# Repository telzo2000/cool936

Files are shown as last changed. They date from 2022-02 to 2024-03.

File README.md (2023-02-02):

# cool936

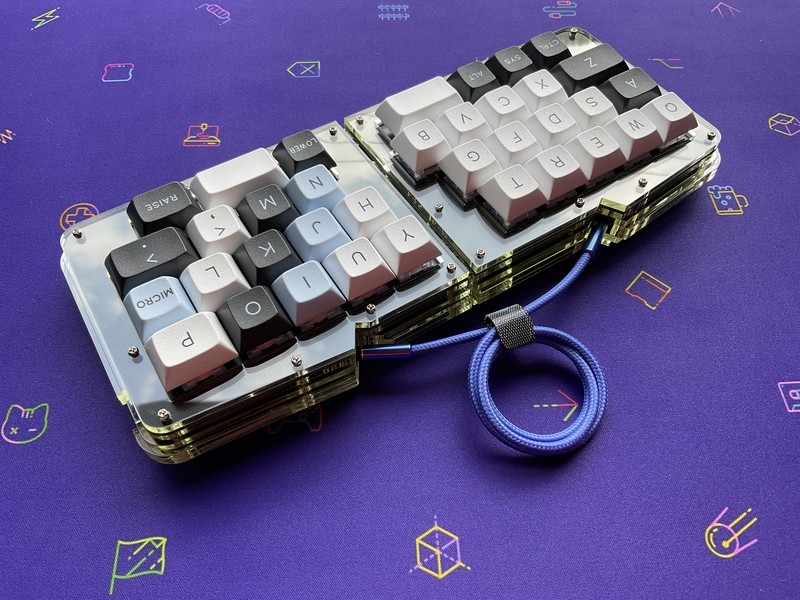
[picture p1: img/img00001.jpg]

## What is cool936?

cool936 is a split keyboard with a [qaz](https://www.cbkbd.com/product/qaz-keyboard-kit) layout.
<br>
[qaz](https://www.cbkbd.com/product/qaz-keyboard-kit)レイアウトの分割キーボードです。
<br>
<br>

## Build Guide
https://github.com/telzo2000/cool936/blob/main/buildguide_for_cool936.md

<br>

## Terms of use(使用条件)

You are free to duplicate the data related to cool936, place an order for PCB, etc. and use it personally.
<br>
cool936に関するデータを複製して、PCB等発注して個人で使用するのは自由です。
<br>
However, it is prohibited to give or receive money such as sales using the data ordered by an individual.
<br>
ただし、個人で発注したデータを使用して販売等、金銭の授受が発生することは禁止です。
<br>
The transfer of money as a manufacturing agent is also included in the prohibition.
<br>
製造代行と称しての金銭の授受も禁止に含まれます。
<br>
<br>

## What are coolxxx?

These keyboards is designed by m.ki.

|cool|another name|keyboard type|MCU|URL|Sales site|
| -- | -- | -- | -- | -- | -- |
|434|MyFirstMini|row|pro micro|none|none|
|445|none|row|pro micro & Raspberry Pi Pico|[Here](https://github.com/telzo2000/cool445)|[Here](https://mki0002ozlet.booth.pm/items/4069834)|
|536|none|column|pro micro|[Here](https://github.com/telzo2000/cool536)|[Here](https://mki0002ozlet.booth.pm/items/4190386)|
|536azcore|none|colum|AZ-CORE|[Here](https://github.com/telzo2000/cool536azcore)|[Here](https://mki0002ozlet.booth.pm/items/4424562)|
|544|Caravellion|column|pro micro|none|none|
|635|none|ortho|pro micro|[Here](https://github.com/telzo2000/cool635-)|none|
|640|none|ortho splite|pro micro & Raspberry Pi Pico|[Here](https://github.com/telzo2000/cool640) |[Here](https://mki0002ozlet.booth.pm/items/3729914)|
|644|none|ortho splite|pro micro|[Here](https://github.com/telzo2000/cool644)|[Here](https://mki0002ozlet.booth.pm/items/3729914)|
|640|none|ortho splite|pro micro & Raspberry Pi Pico | [Here](https://github.com/telzo2000/cool640)|[Here](https://mki0002ozlet.booth.pm/items/3729914) |
|640|none|ortho splite|pro micro & Raspberry Pi Pico|[Here](https://github.com/telzo2000/cool640)|[Here](https://mki0002ozlet.booth.pm/items/3729914)|
|650|none|ortho splite|pro micro|[Here](https://github.com/telzo2000/cool650)|[Here](https://mki0002ozlet.booth.pm/items/3585417)|
|664|none|ortho splite|pro micro|[Here](https://github.com/telzo2000/cool664)|[Here](https://mki0002ozlet.booth.pm/items/4328726)|
|753|none|row|pro micro|none|none|
|756|none|row|pro micro|[Here](https://github.com/telzo2000/cool756)|[Here](https://mki0002ozlet.booth.pm/items/4491960)|
|836A|none|alice|pro micro|[Here](https://github.com/telzo2000/cool836A)|[Here](https://mki0002ozlet.booth.pm/items/2542223)|
|836pico|none|alice|Raspberry Pi Pico|[Here](https://github.com/telzo2000/cool836pico)|[Here](https://mki0002ozlet.booth.pm/items/3391829)|
|836rp|none|alice|RP2040-Zero|[Here](https://github.com/telzo2000/cool836pico)|[Here](https://mki0002ozlet.booth.pm/items/3599330)|
|844|none|alice|pro micro|[Here](https://github.com/telzo2000/cool844)|[Here](https://mki0002ozlet.booth.pm/items/2805606)|
|844V2|none|alice|pro micro|[Here](https://github.com/telzo2000/cool844V2)|[Here](https://mki0002ozlet.booth.pm/items/3267681)|
|847|none|alice|pro micro|[Here](https://github.com/telzo2000/cool847)|[Here](https://mki0002ozlet.booth.pm/items/3358065)|
|936|none|row splite|pro micro|[Here](https://github.com/telzo2000/cool936)|none|
|939|none|row splite|pro micro|[Here](https://github.com/telzo2000/cool939)|none|
|943S|none|row splite|pro micro|[Here](https://github.com/telzo2000/cool943S)|[Here](https://mki0002ozlet.booth.pm/items/2901779)|
|950S|none|row splite|pro micro|[Here](https://github.com/telzo2000/cool950S)|[Here](https://mki0002ozlet.booth.pm/items/3160071)|
|959|none|alice splite|pro micro|[Here](https://github.com/telzo2000/cool959)|none|

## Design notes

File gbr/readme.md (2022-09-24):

## gbr data

ver.1.1 is a PCB compatible with sk6812mini-e.
<br>
ver.1.1はsk6812mini-eに対応したPCBです。
<br>
<br>
ver.151 is a PCB compatible with LED tape.
<br>
ver.151はLEDテープに対応したPCBです。
<br>

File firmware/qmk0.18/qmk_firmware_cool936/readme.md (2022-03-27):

# cool936

cool936

*A short description of the keyboard/project*

* Keyboard Maintainer: [m.ki](https://github.com/telzo2000)
* Hardware Supported: *The PCBs, controllers supported*
* Hardware Availability: *Links to where you can find this hardware*

Make example for this keyboard (after setting up your build environment):

    make cool936:default

Flashing example for this keyboard:

    make cool936:default:flash

See the [build environment setup](https://docs.qmk.fm/#/getting_started_build_tools) and the [make instructions](https://docs.qmk.fm/#/getting_started_make_guide) for more information. Brand new to QMK? Start with our [Complete Newbs Guide](https://docs.qmk.fm/#/newbs).

## Bootloader

Enter the bootloader in 3 ways:

* **Bootmagic reset**: Hold down the key at (0,0) in the matrix (usually the top left key or Escape) and plug in the keyboard
* **Physical reset button**: Briefly press the button on the back of the PCB - some may have pads you must short instead
* **Keycode in layout**: Press the key mapped to `RESET` if it is available

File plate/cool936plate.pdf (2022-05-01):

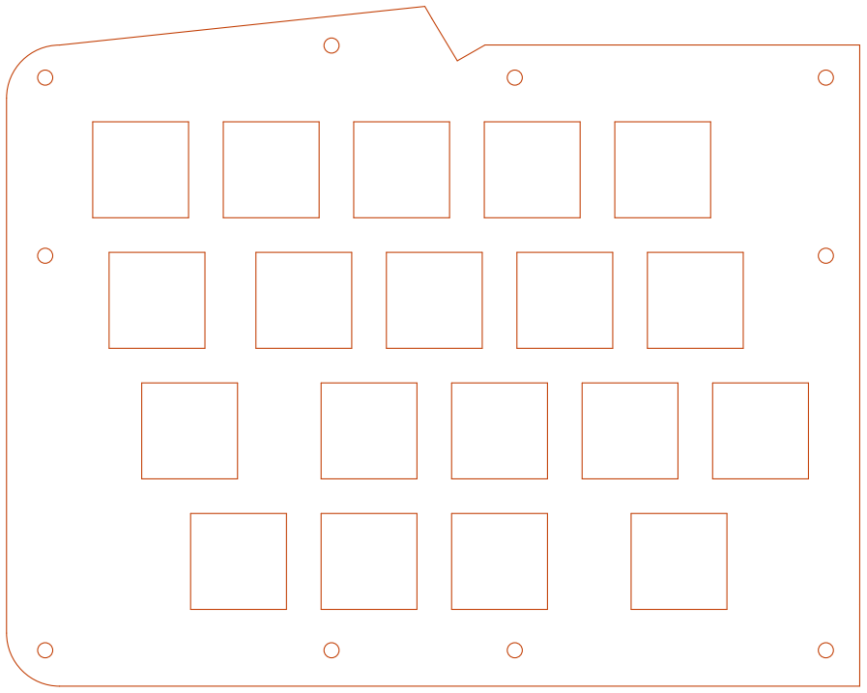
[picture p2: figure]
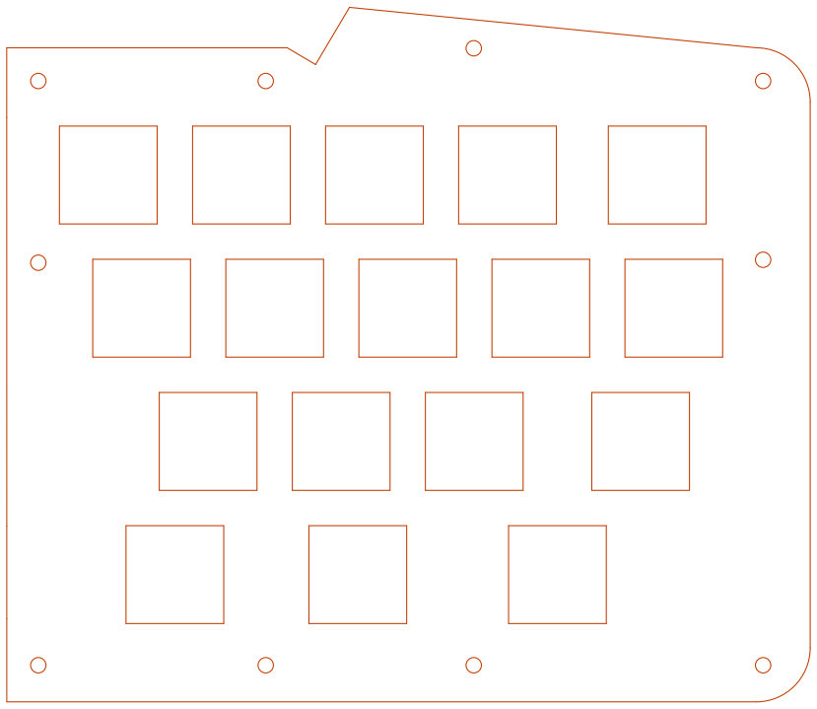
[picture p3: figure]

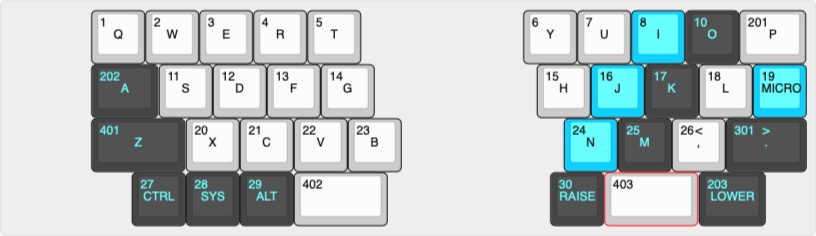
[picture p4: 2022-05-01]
first_design/cool936sbydss_micro-3.jpg

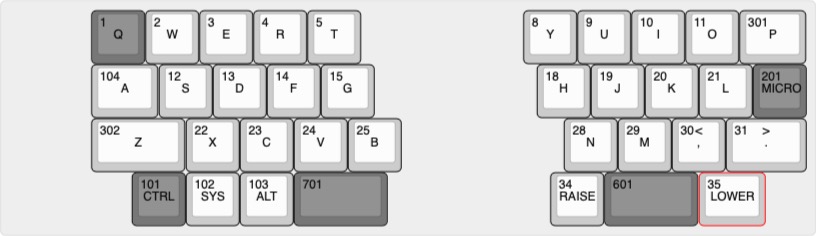
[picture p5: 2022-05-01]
first_design/cool936s.jpg

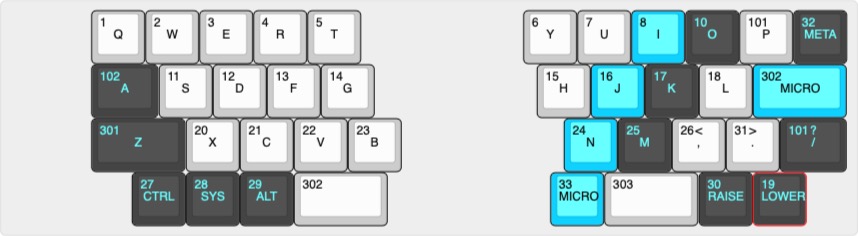
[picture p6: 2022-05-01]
first_design/cool939sbydss_micro-3.jpg

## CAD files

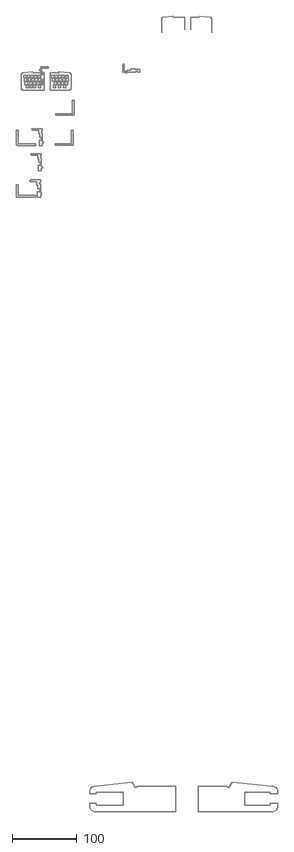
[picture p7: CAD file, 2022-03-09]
case/cool936casedesign02.dxf
404.4 x 1230.5

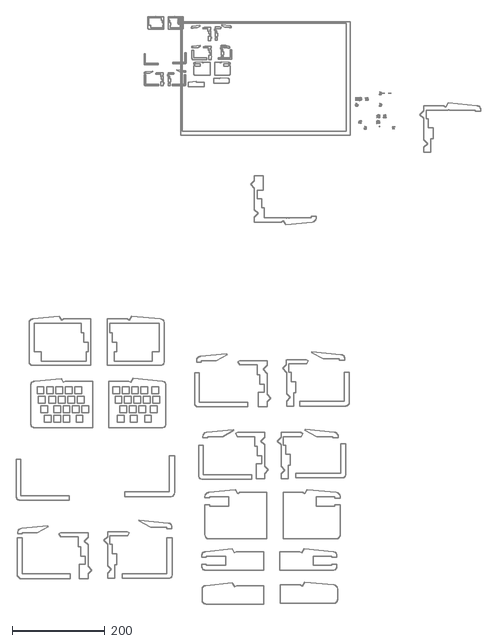
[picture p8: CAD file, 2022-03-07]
case_wide/Laser_450x300_template_inkscape_cool936.dxf
999.1 x 1264.5

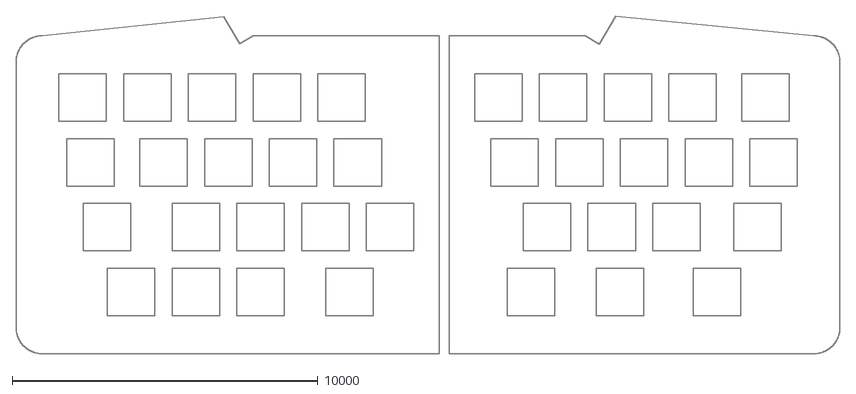
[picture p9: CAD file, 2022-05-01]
plate/cool936plate.dxf
26935.8 x 11036.7

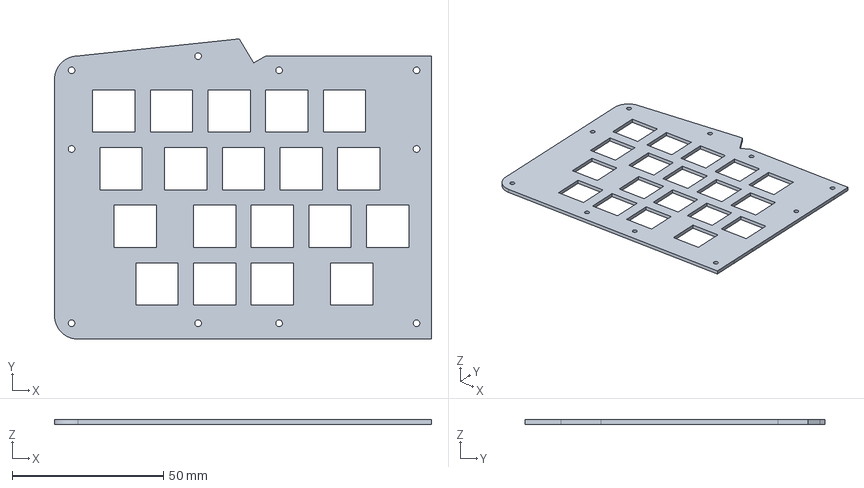
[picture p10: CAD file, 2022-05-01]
plate/plate_left/cool936plateleft.step
124.5 x 99.2 x 1.60 mm

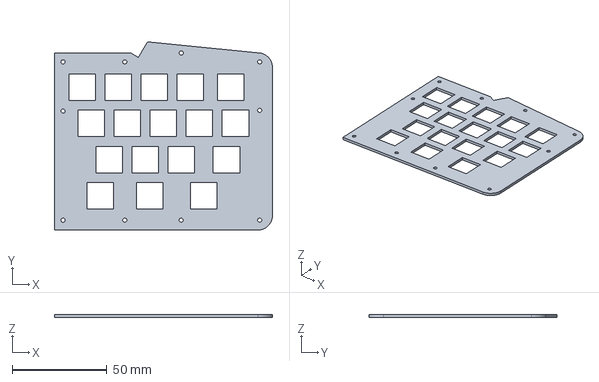
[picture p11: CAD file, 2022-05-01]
plate/plate_right/cool936plateright.step
115.0 x 99.3 x 1.60 mm

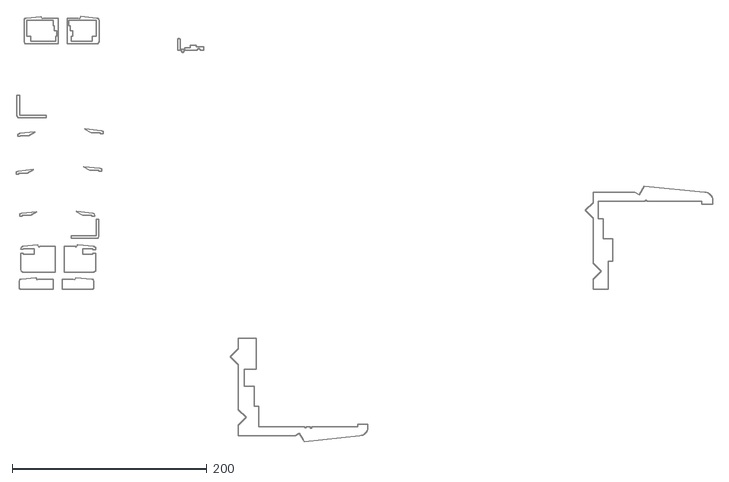
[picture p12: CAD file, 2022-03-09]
case/cool936casedesign01.dxf
714.9 x 436.3

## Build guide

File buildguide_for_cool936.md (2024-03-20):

# Build Guide

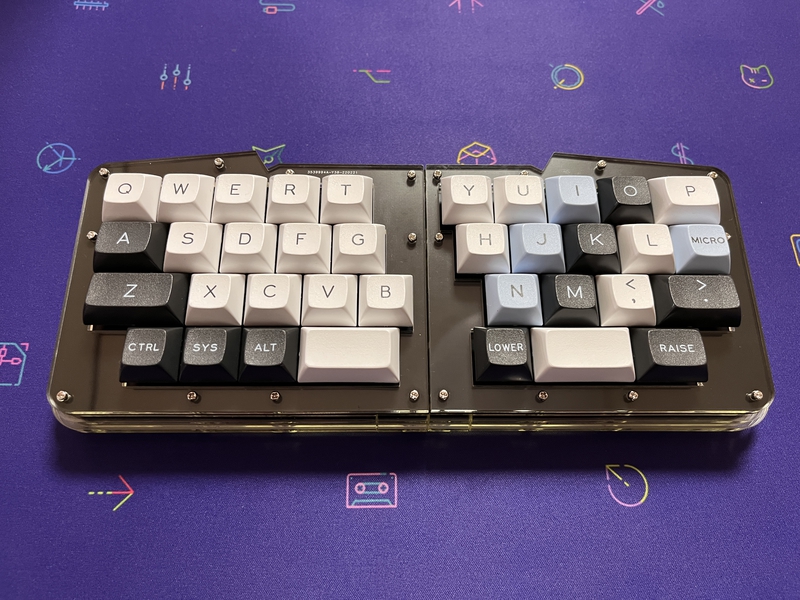
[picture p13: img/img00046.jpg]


## Parts List
Information as of March 8, 2022<br>
令和４年５月23日時点の情報
|番号| 名前 | 数 | 備考 | 調達先の例 | 参考価格 |
|:-|:-|:-|--|--|--|
|1|PCB Leftside|1|108.27 mm<br>* 86.87 mm|JLCPCB|５枚9.6ドル|
|2|PCB Rightside|1|98.87 mm<br>* 87.43 mm|↑|５枚で3.7ドル|
|3|Switch Plate|1|FR-4<br>左右一体で発注<br>242.4 mm<br>* 99.3 mm|↑|５枚で33.4ドル|
|4|Top Plate|左右１枚ずつ|アクリル3mm|※１|※２|
|5|Middle Plate|４層分（20個に分割）|アクリル3mm|※１|※２|
|6|Bottom Plate|２層分|アクリル3mm|※１|※２|
|7|M2ネジ|32|8mm<br>TopPlate側から20本挿入<br>BottomPlate側（奥）から12本挿入|DIYショップ等|10本程度で100円|
|8|M2ネジ|8|4mm<br>BottomPlate側（手前）から挿入|DIYショップ等|10本程度で100円|
|9|M2スペーサー|20|11mm丸型※３|[ヒロスギネット](https://www.hirosugi-net.co.jp/shop/default.aspx)<br>[遊舎工房](https://shop.yushakobo.jp)等|20個で748円（税込）@ヒロスギネット|
|10|Diode|36本|リードタイプ、SMDのどちらでも可|[遊舎工房](https://shop.yushakobo.jp)<br>[TALP keyboard](https://talpkeyboard.net)|100個で220円（税込）|
|11|Reset Switch|2|タクタイルスイッチとも|[遊舎工房](https://shop.yushakobo.jp)<br>[TALP keyboard](https://talpkeyboard.net)|1個で11円（税込）|
|12|Switch Socket|36|Cherry MX互換|[遊舎工房](https://shop.yushakobo.jp)<br>[TALP keyboard](https://talpkeyboard.net)|10個で165円（税込）|
|13|TRRS Jack|2||[遊舎工房](https://shop.yushakobo.jp)<br>[TALP keyboard](https://talpkeyboard.net)等|１個55円（税込）|
|14|pro micro|PCB１枚につき１個|ピンヘッダが必要|[遊舎工房](https://shop.yushakobo.jp)<br>[TALP keyboard](https://talpkeyboard.net)|時価|
|15|キーキャップ|36|[DSS Micro](https://mechvault.net/products/dss-micro-keycap-set)推奨<br>※４|[遊舎工房](https://shop.yushakobo.jp)<br>[TALP keyboard](https://talpkeyboard.net)|1個で100円前後<br>キーキャップセットで3000円程度から|
|16|TRRSケーブル|１本||[遊舎工房](https://shop.yushakobo.jp)<br>[TALP keyboard](https://talpkeyboard.net)等|300円程度から|
|17|ゴム足|８|任意|DIYショップ等|100円程度|

※１　[工房merge+](https://www.emergeplus.jp/laser-cutting-service/contact/)、[遊舎工房](https://shop.yushakobo.jp/collections/services/products/lasercut)、[Elecrow](https://www.elecrow.com/acrylic-cutting.html) 等でアクリル加工が可能。
<br>
※２　The [case folder](https://github.com/telzo2000/cool936/tree/main/case) contains two 300mmX300mm acrylic files, and the [case_wide folder](https://github.com/telzo2000/cool936/tree/main/case_wide) contains one 300mmX450mm acrylic file.
<br>
 [caseフォルダ](https://github.com/telzo2000/cool936/tree/main/case)には、300mmX300mmアクリル２枚、[case_wideフォルダ](https://github.com/telzo2000/cool936/tree/main/case_wide)には、300mmX450mmアクリル１枚にまとめられたファイルがある。
 <br>
※３　Due to the difference in acrylic accuracy, 11mm, which is slightly shorter than 12mm, is more suitable.
<br>アクリルの精度差により、12mmよりやや短い11mmの方が適当である。
<br>
※４　Since the cool936 is a QAZ-like keyboard, there are few keycaps to which the legend applies.
<br>
cool936は、QAZ的なキーボードなので、レジェンドが適応するキーキャップは少ない。
<br><br>
## 組み立て

### 0 アクリル部品の確認

cool936では、トッププレート、ミドルプレート、ボトムプレートにアクリル部品を使用するアクリル積層ケースとなっています。
<br>
トッププレートは左右それぞれ1枚ずつあります。
<br>
ミドルプレートは左右それぞれ４層となります。１層が２枚または３枚で構成されています。
<br>
ボトムプレートは左右それぞれ２層となります。大、小に分けられます。
<br>

### 左側<br>

トッププレート
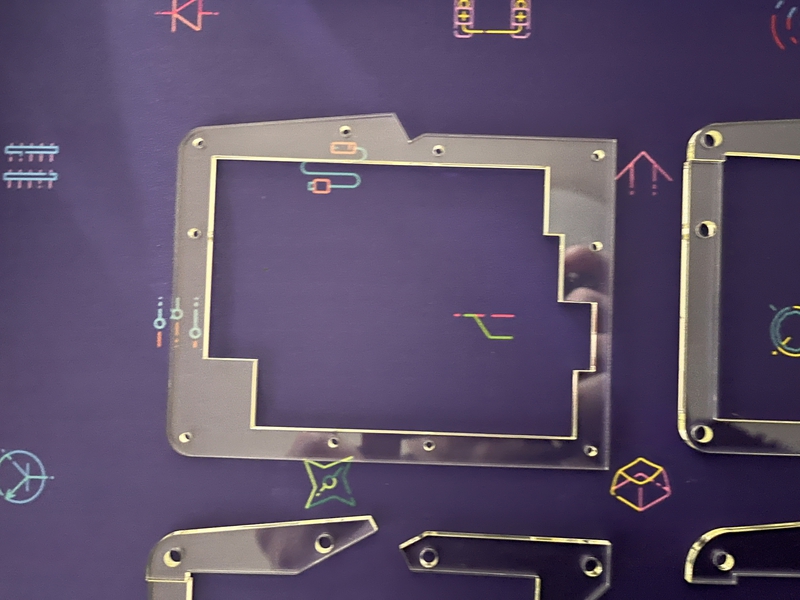
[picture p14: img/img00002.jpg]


ミドルプレート１
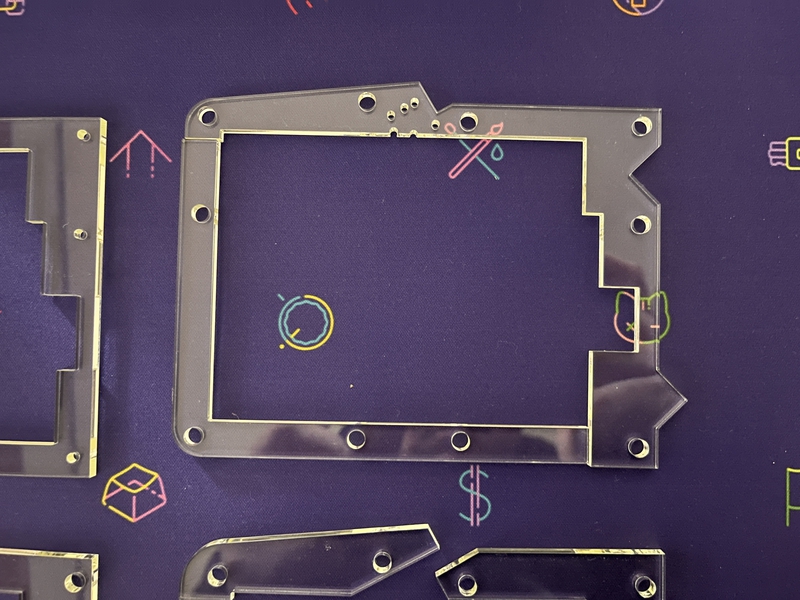
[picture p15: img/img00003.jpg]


ミドルプレート２
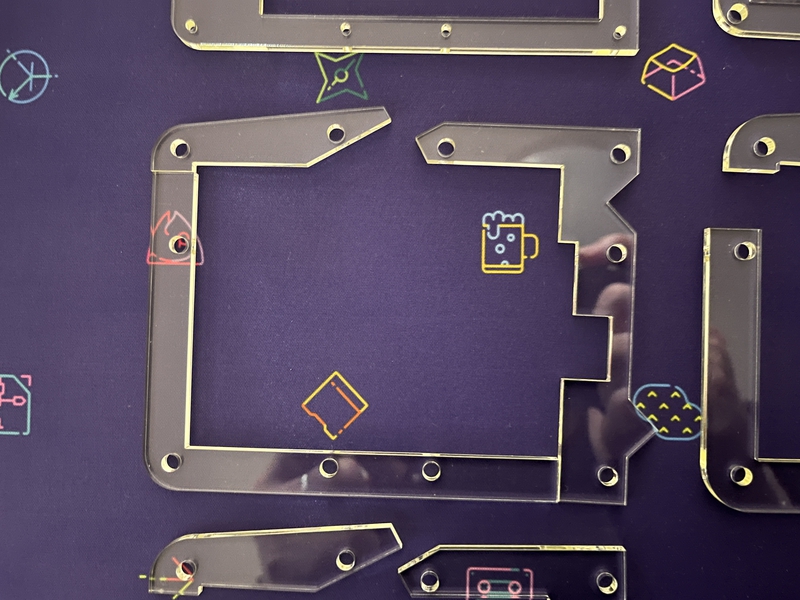
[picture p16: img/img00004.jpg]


ミドルプレート３・４（同じ形状）
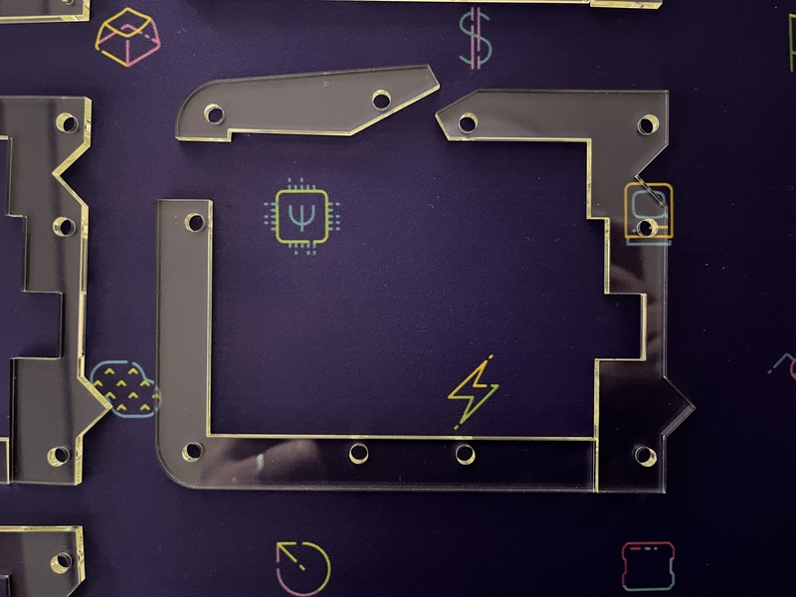
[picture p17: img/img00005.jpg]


ボトムプレート大
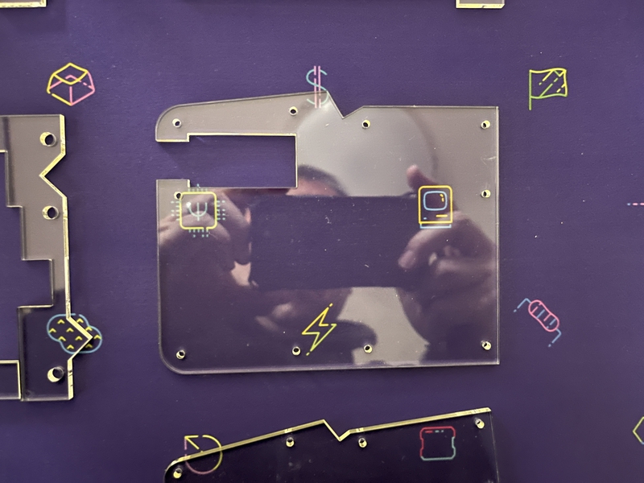
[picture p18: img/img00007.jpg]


ボトムプレート小
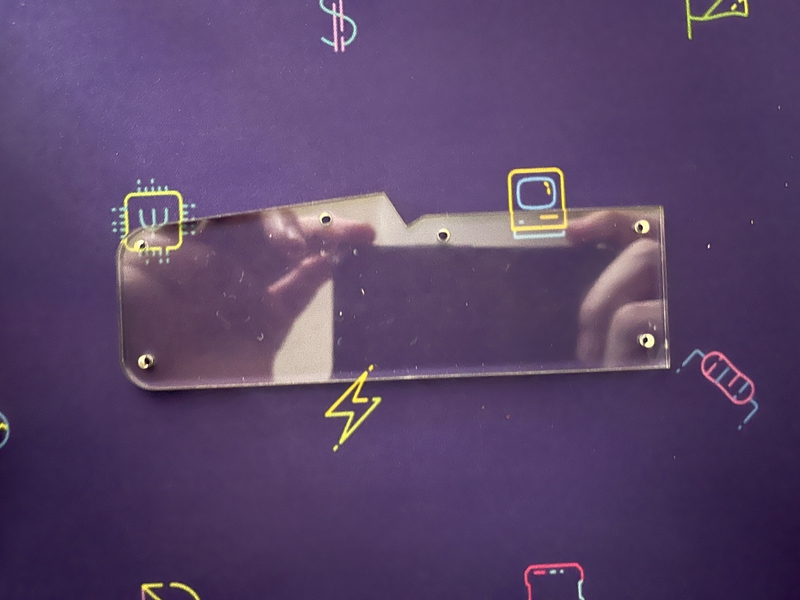
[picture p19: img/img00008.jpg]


### 右側<br>

トッププレート
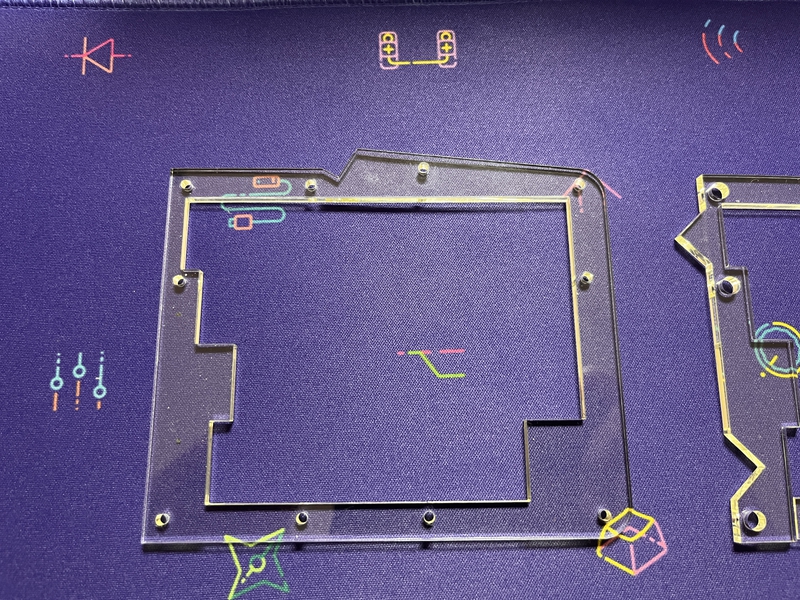
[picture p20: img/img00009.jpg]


ミドルプレート１
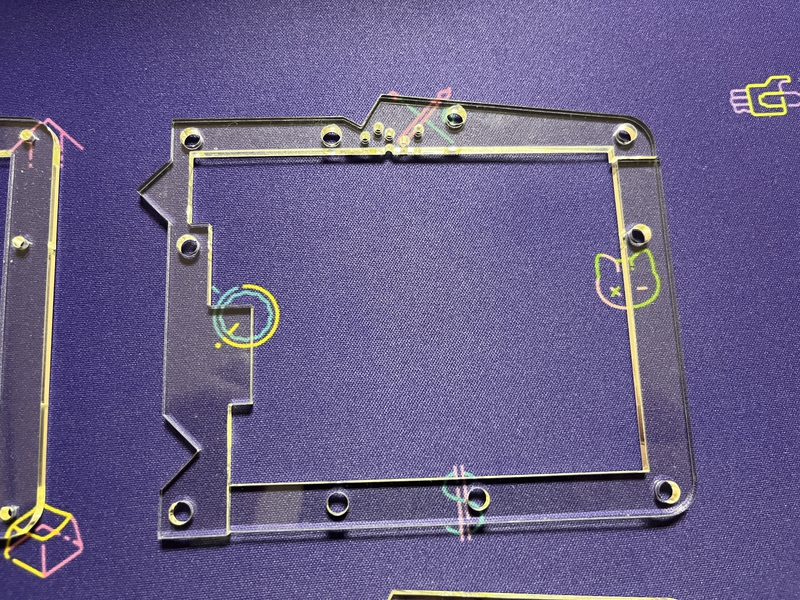
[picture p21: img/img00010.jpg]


ミドルプレート２
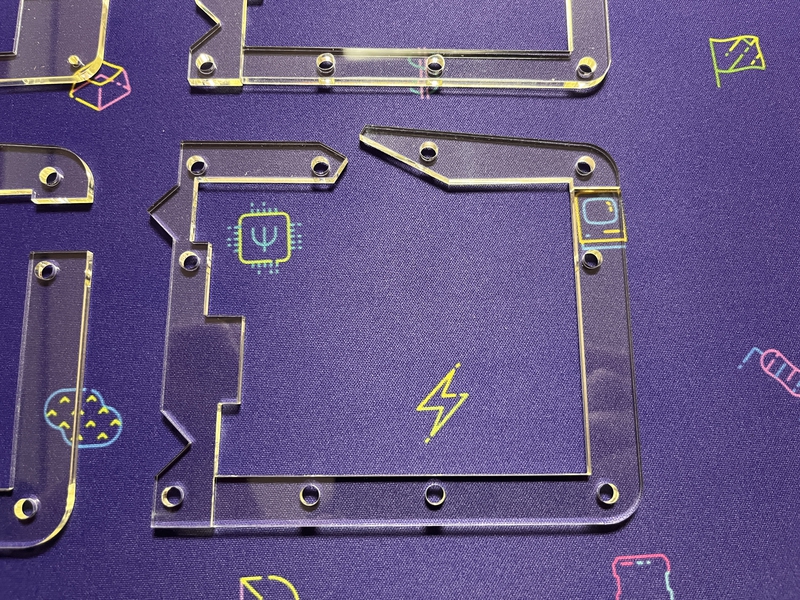
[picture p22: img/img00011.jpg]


ミドルプレート３・４（同じ形状）
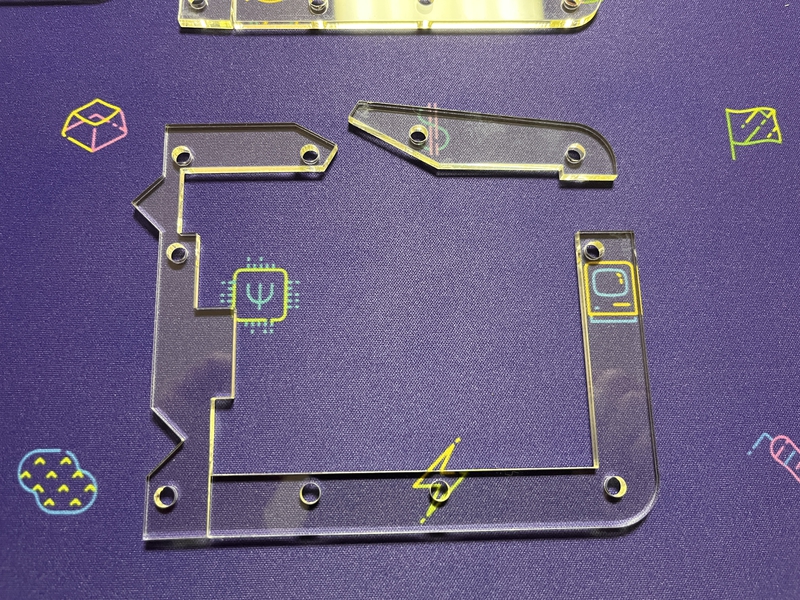
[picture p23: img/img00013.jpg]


ボトムプレート大
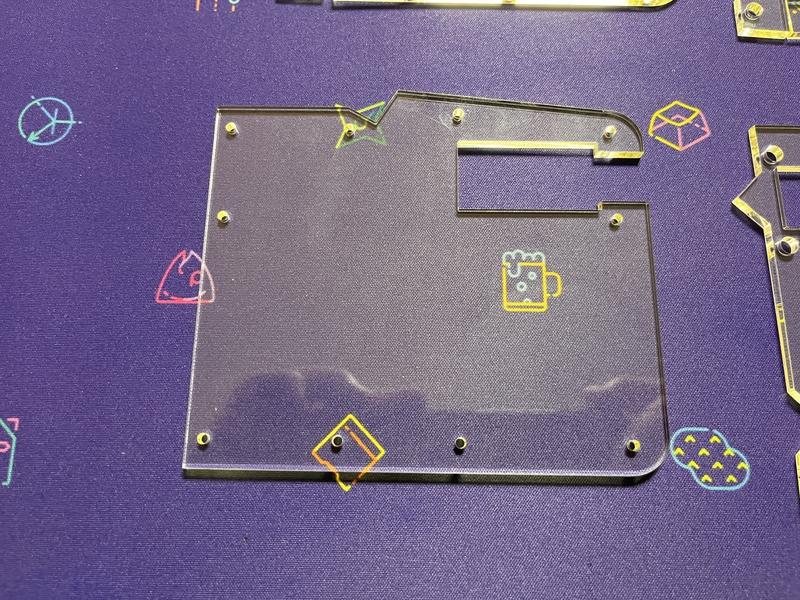
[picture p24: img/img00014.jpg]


ボトムプレート小
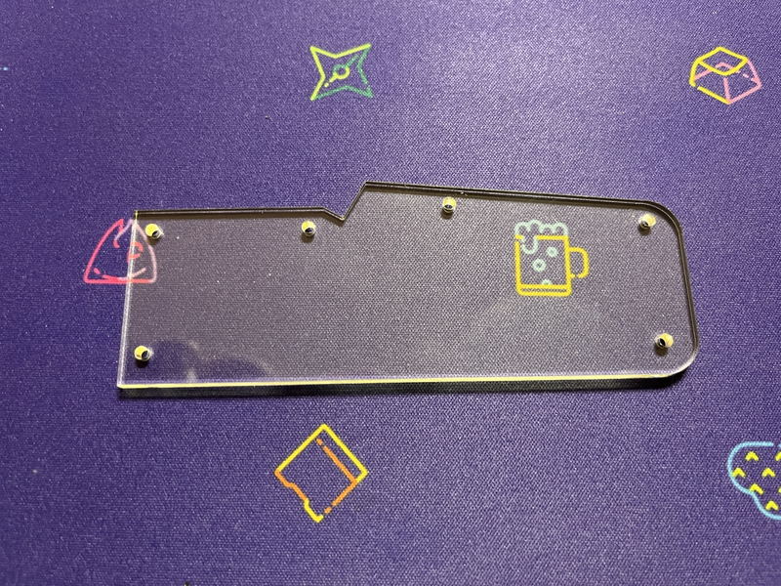
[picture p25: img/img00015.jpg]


### 1 ダイオードのハンダ付け

左右のPCBにそれぞれ、ダイオードをハンダ付けします。
<br>
構造上、どちらの面にハンダ付けしても問題ありませんが、
竜のイラストがある面にダイオードのハンダ付けをしてください。
<br>

### 2 スイッチソケットのはんだ付け

竜のイラストがある面に、スイッチソケットをハンダ付けします。
<br>
socketという文字が隠れるように、スイッチソケットを乗せると方向を間違えずに、
ハンダ付けができます。
<br><br>

### 3 リセットスイッチ、TRRSジャックのはんだ付け

竜のイラストがある面に、リセットスイッチ、TRRSジャックをハンダ付けします。
<br>
ハンダ付けした後、リセットスイッチとTRRSジャックのはみ出た足は、ニッパー等で切断しておいてください。
<br><br>

### 4 pro microの取り付け

竜のイラストがある面に、pro microを（できればスプリングヘッダを用いて）ハンダ付けしてください。
<br>
pro microの向きに注意が必要です。
<br>
pro microの部品が実装されている面が、下になるようにハンダ付けをしてください。
実際、逆に取り付けようとすると、pro microの部品と、先ほどハンダ付けしたスイッチソケットなどが干渉するので、
ハンダ付けができないと思います。
<br><br>

### 5 LEDのハンダ付け（任意）

後日、執筆予定。
<br><br>

### 6 仮テスト

一度スイッチを装着するか、ピンセットで接続するか等の方法でキー入力ができるかテストします。
<br>
[REMAP](https://remap-keys.app/)でファームウェアをインストールしてください。
<br>
[ここ](https://config.qmk.fm/#/test)でタイピングテストを行い、導通の確認をしてください。
<br>
すべてのキーの入力が確認できましたら、次の段階に進んでください。
<br>
うまくいかないキー入力がありましたら、温めたハンダゴテで、該当するスイッチソケット等のハンダを温め直してください。
<br><br>

参考<br>

https://github.com/telzo2000/Hello_keyboard/blob/main/readme_about_firmware.md

### 7　アクリルケースの組み立て
ボトムプレートからミドルプレートの順に、アクリル積層ケースを組み立てます。
<br>M２スペーサー11mmを20本（左右10本ずつ）、M２ネジ8mmを12本（左右6本ずつ）、２ネジ4mmを８本（左右４本ずつ）とミドルプレート２・３・４、ボトムプレート大・小を用意します。
<br>
### 左側

①ボトムプレート小から大の順で、M２ネジ8mmを挿しこみ、反対側で、M２スペーサーで固定する。

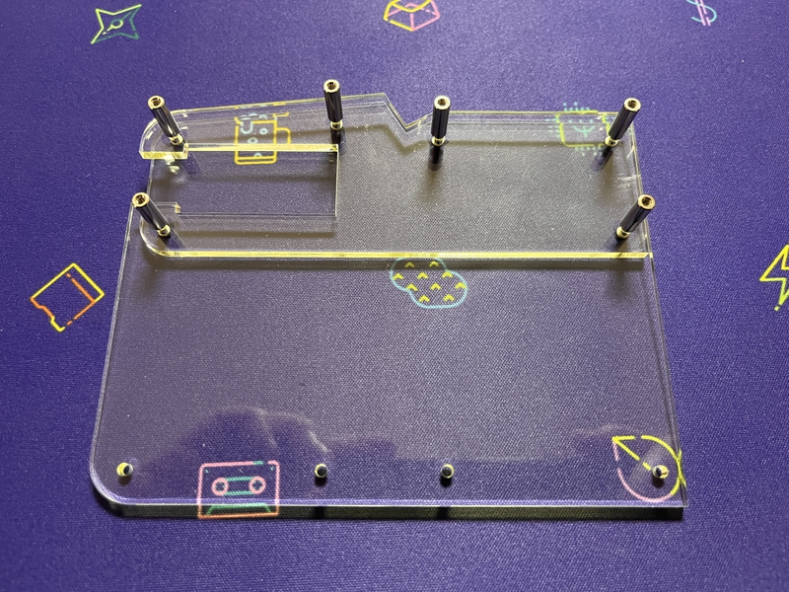
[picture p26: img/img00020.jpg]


②ボトムプレート大の残り４箇所に、M２ネジ4mmを挿しこみ、反対側で、M２スペーサーで固定する。

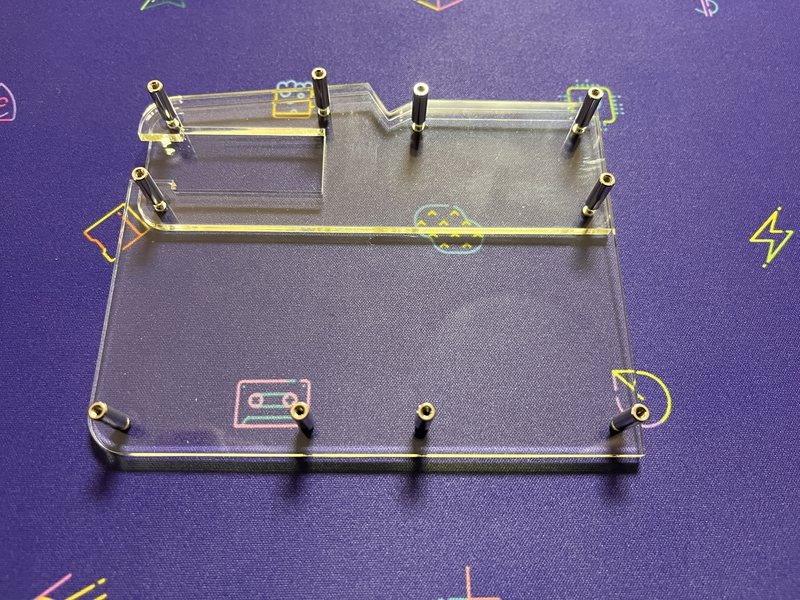
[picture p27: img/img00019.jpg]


③ミドルプレート３・４を重ねる。

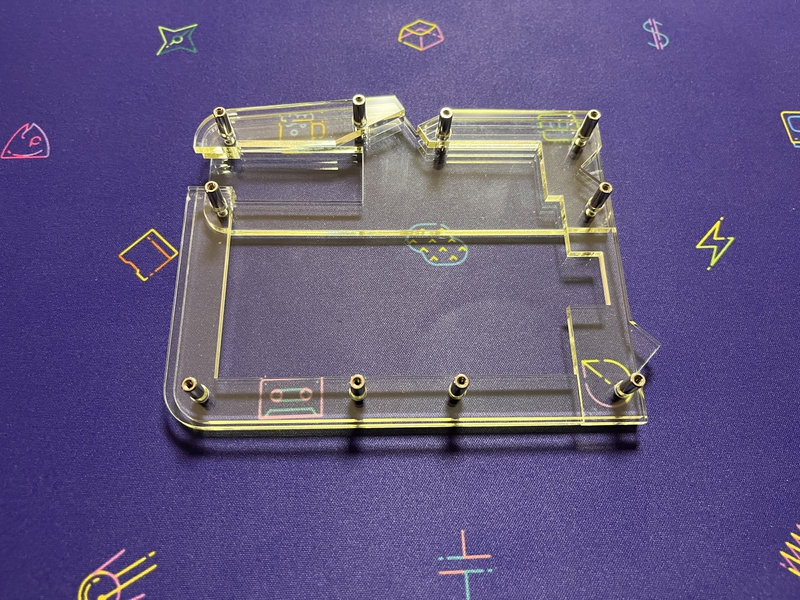
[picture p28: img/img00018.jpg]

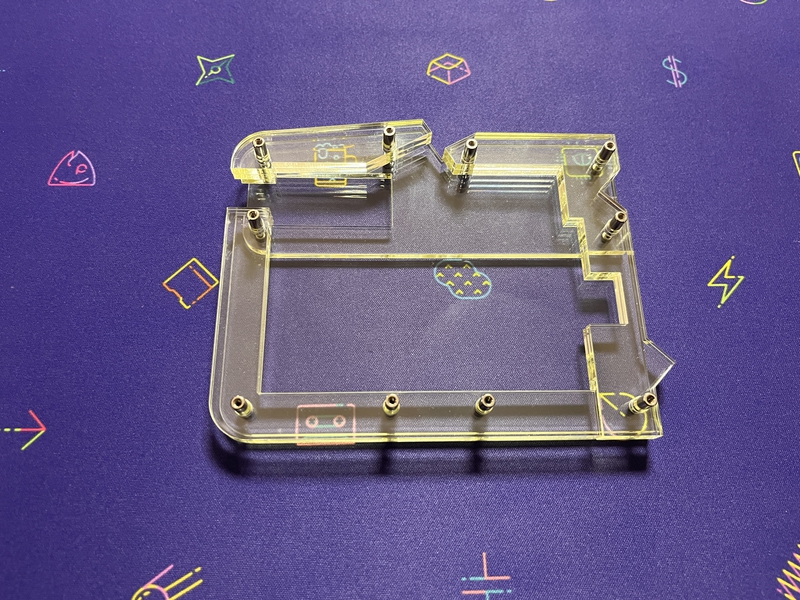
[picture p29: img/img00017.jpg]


④ミドルプレート２を重ねる。

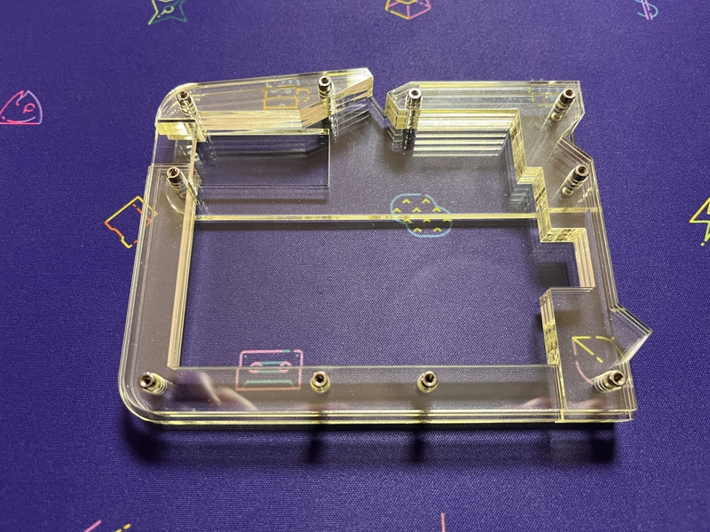
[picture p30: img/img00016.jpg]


### 右側

①ボトムプレート小から大の順で、M２ネジ8mmを挿しこみ、反対側で、M２スペーサーで固定する。

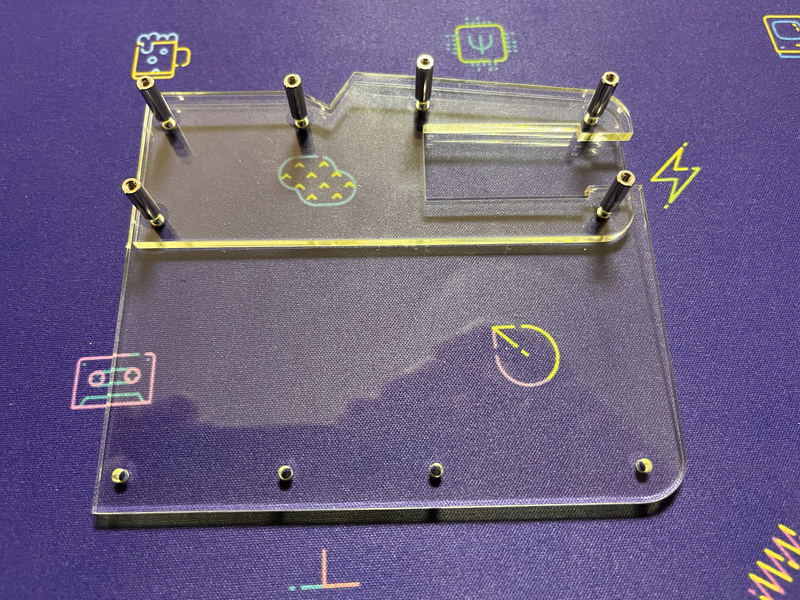
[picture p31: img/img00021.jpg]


②ボトムプレート大の残り４箇所に、M２ネジ4mmを挿しこみ、反対側で、M２スペーサーで固定する。

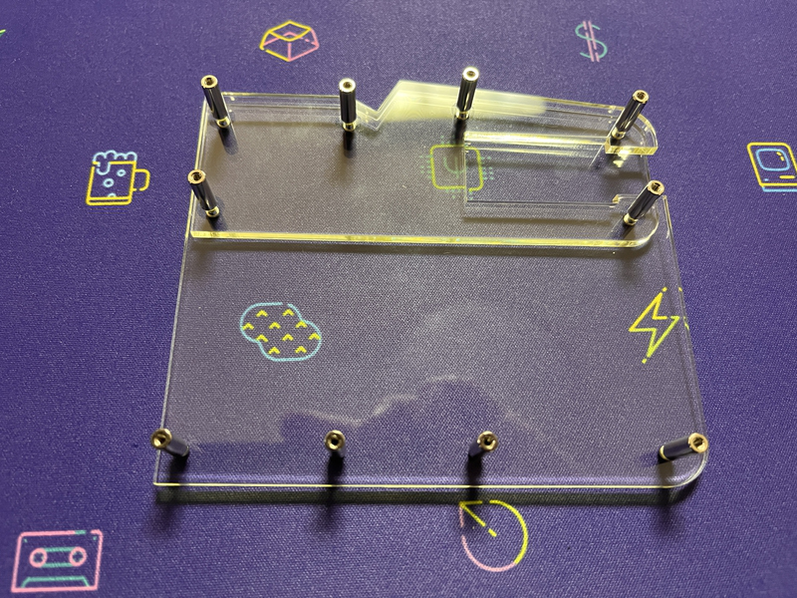
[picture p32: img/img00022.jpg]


③ミドルプレート３・４を重ねる。

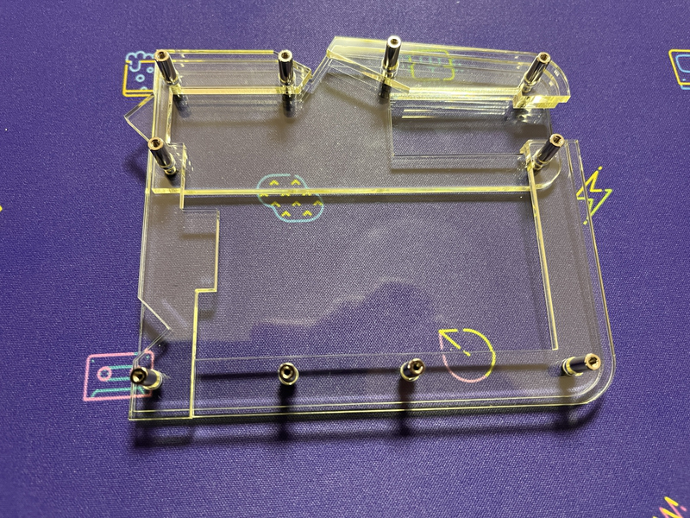
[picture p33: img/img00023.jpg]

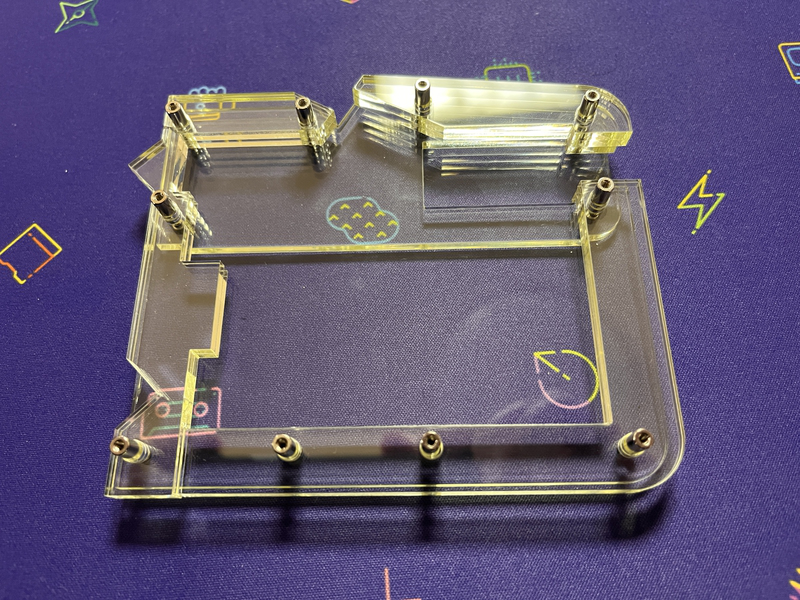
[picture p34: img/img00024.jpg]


④ミドルプレート２を重ねる。

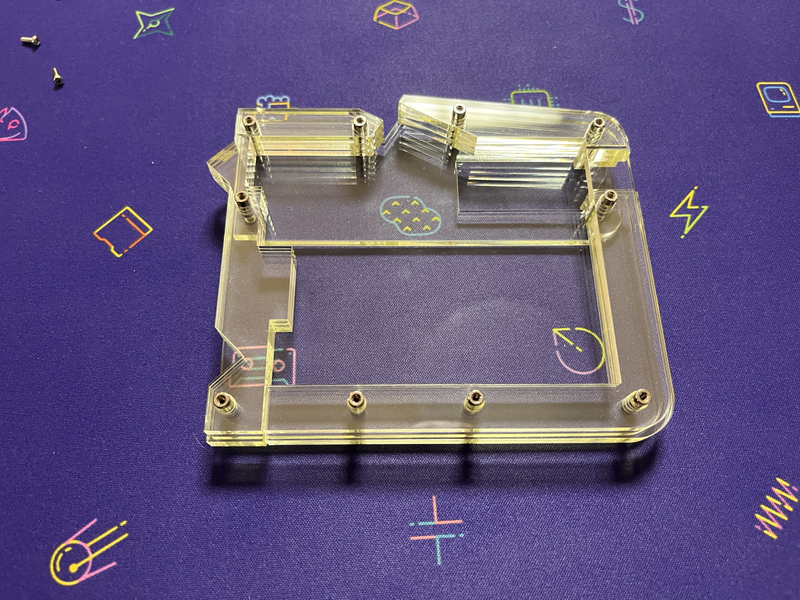
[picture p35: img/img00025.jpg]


### 8 トッププレート部分の組み立て

キースイッチをスイッチプレート及び、PCBのスイッチソケットに装着します。
<br>
M２ネジ8mmを20本（左右10本ずつ）とトッププレート、ミドルプレート１、アクリルケースを用意します。
### 左側

最初、スイッチプレートの穴4箇所程度に、キースイッチを挿しこみます。

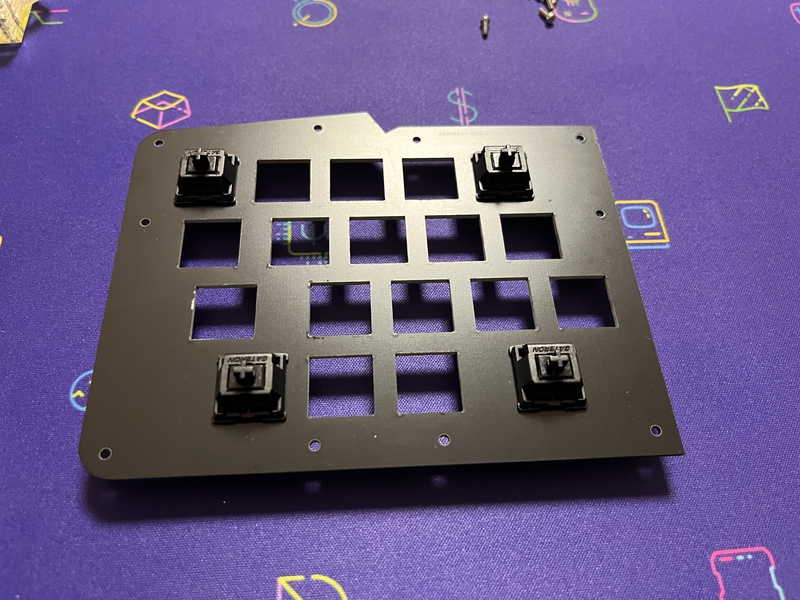
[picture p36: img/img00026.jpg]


裏返します。
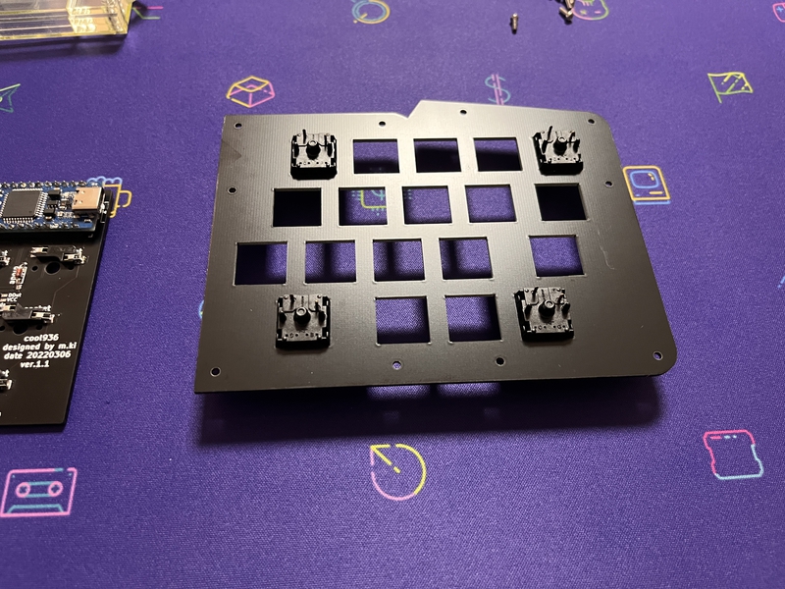
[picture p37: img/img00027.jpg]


次に、スイッチプレートに、ミドルプレート１をのせます。

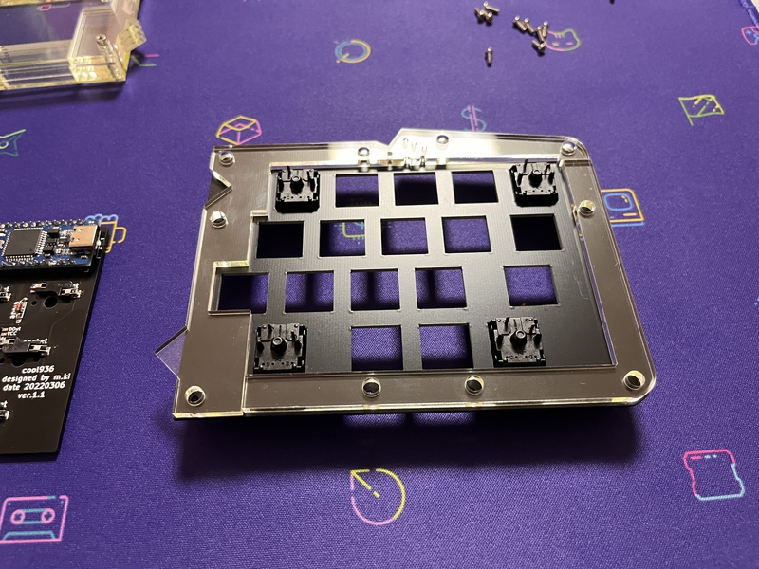
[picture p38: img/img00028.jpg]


PCBをキースイッチに挿しこみます。

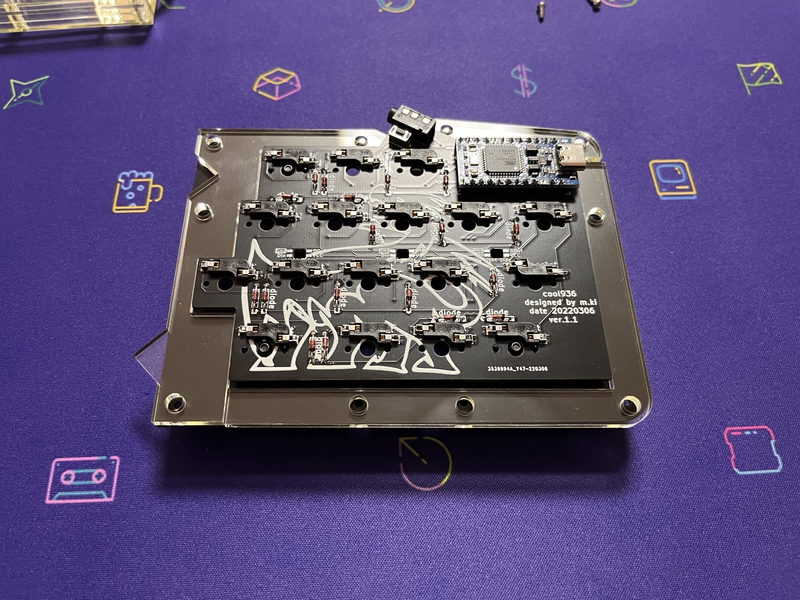
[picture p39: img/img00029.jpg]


向きを戻して、他のキースイッチも取り付けします。

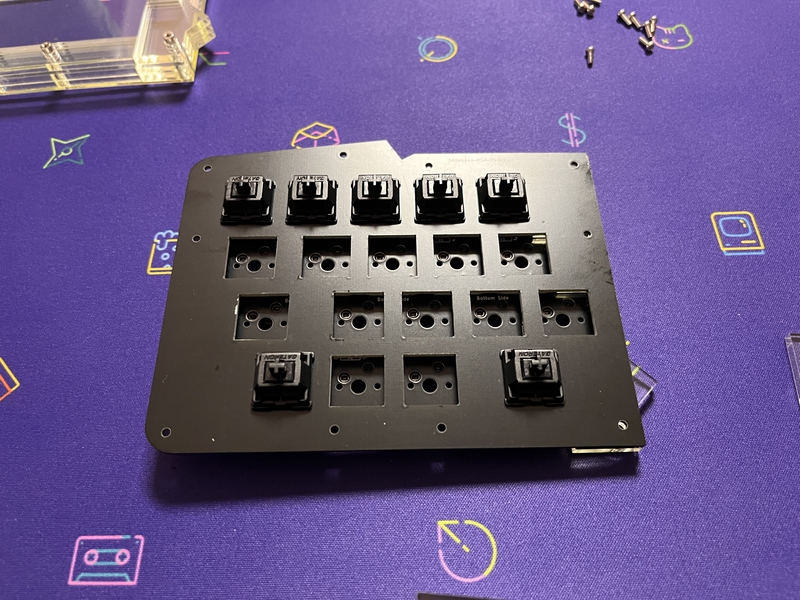
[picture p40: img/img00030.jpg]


その際、ミドルプレート１の一部が外れていても大丈夫です。

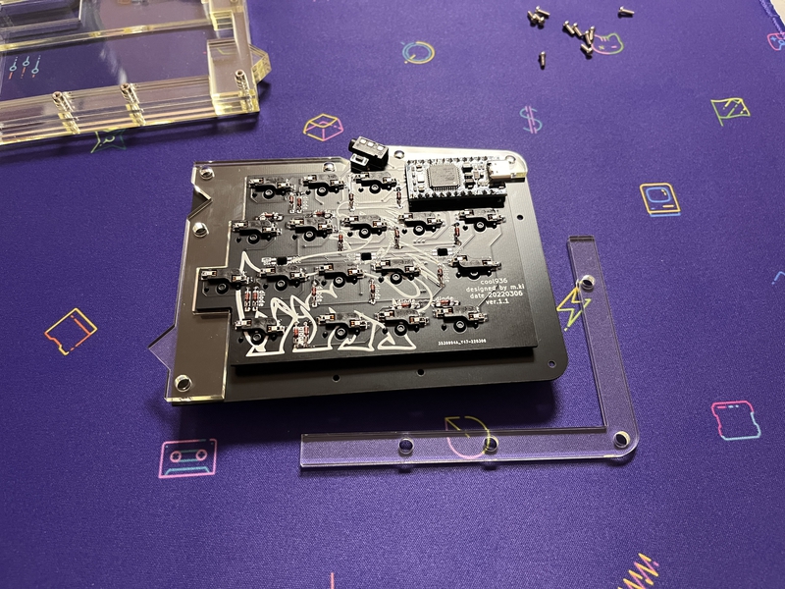
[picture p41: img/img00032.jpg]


すべてのキースイッチを取り付けたら、先ほど作ったアクリルケースと組み合わせます。その際、外れていたミドルプレート１の一部を忘れないで組み合わせてください。

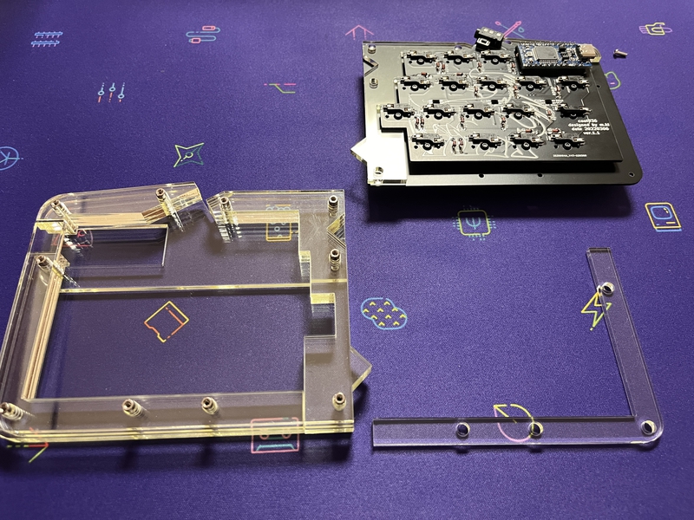
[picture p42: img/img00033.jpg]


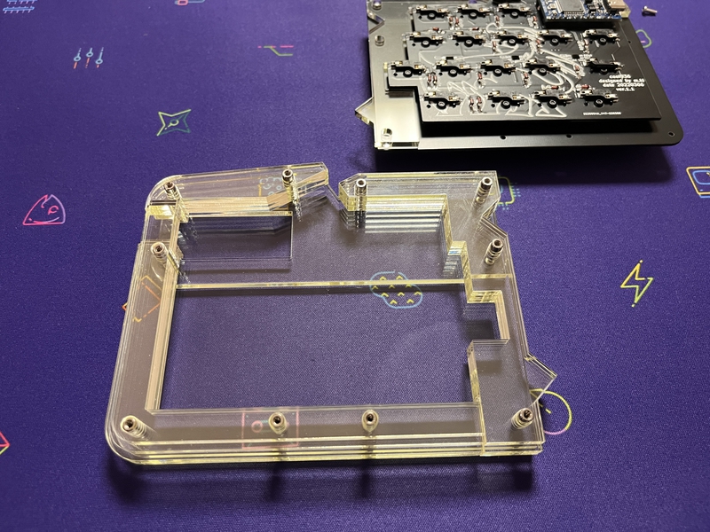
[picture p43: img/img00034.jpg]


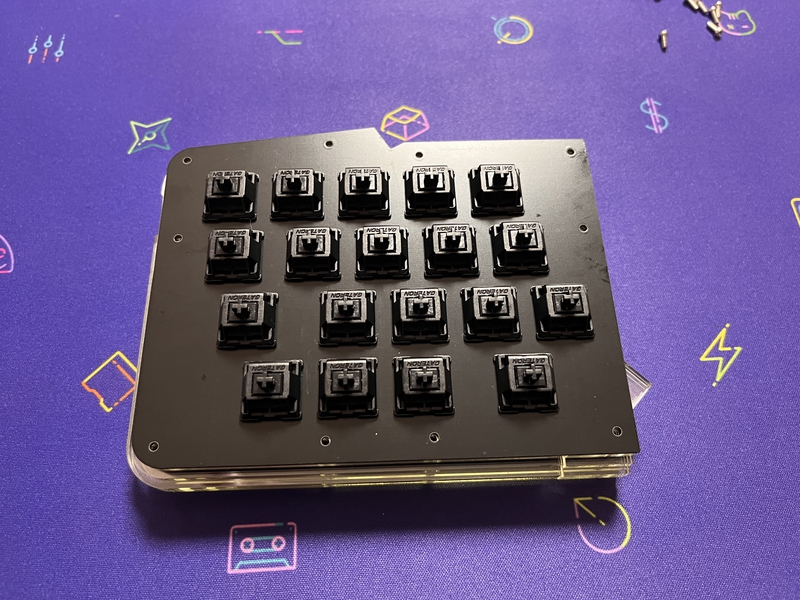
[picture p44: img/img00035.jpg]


トッププレートをのせます。

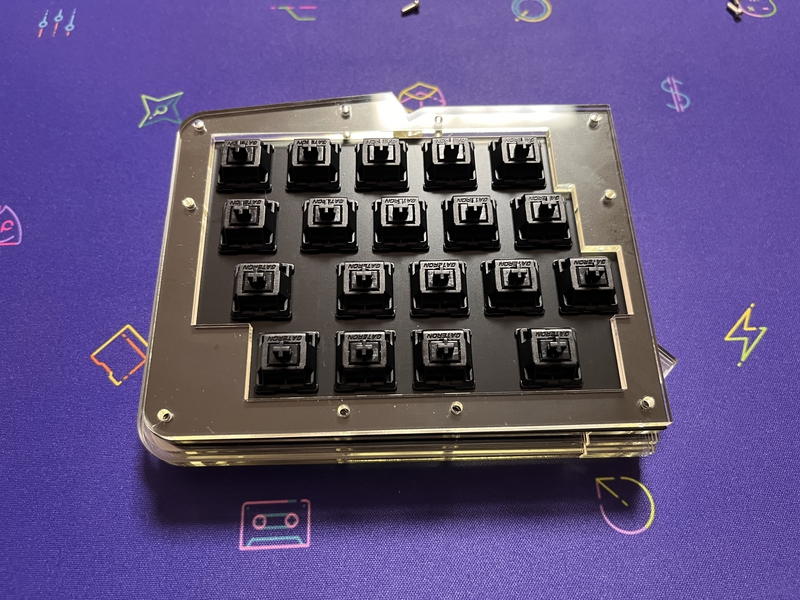
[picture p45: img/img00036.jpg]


M２ネジで固定します。

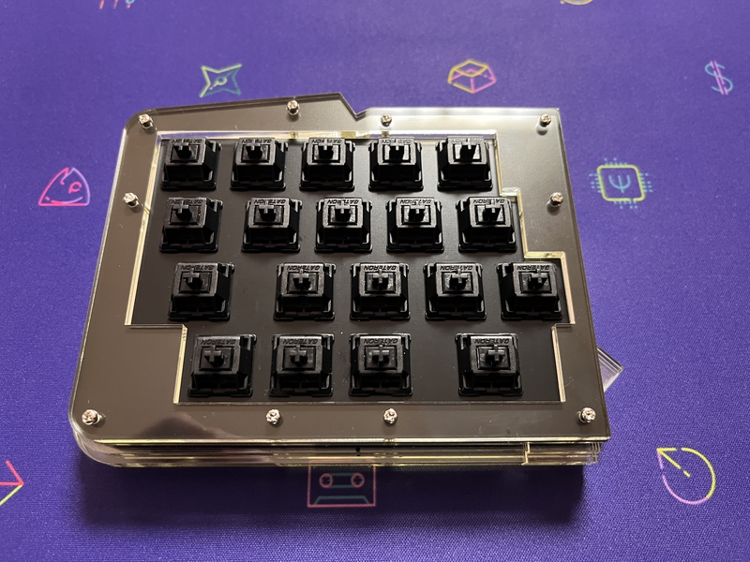
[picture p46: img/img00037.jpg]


### 右側

最初、スイッチプレートの穴4箇所程度に、キースイッチを挿しこみます。

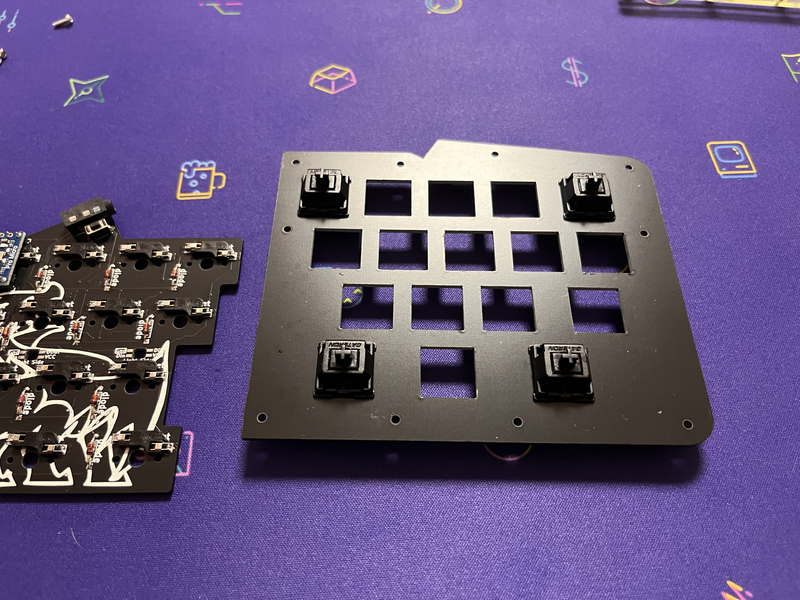
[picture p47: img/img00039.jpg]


裏返します。次に、スイッチプレートに、ミドルプレート１をのせます。
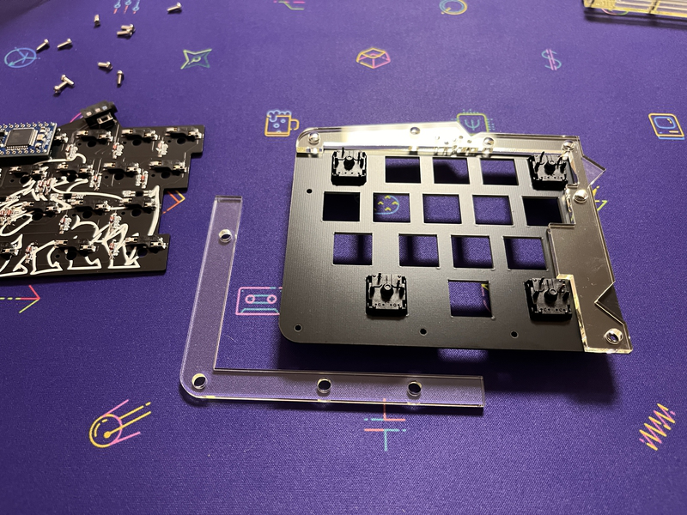
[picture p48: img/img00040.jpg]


PCBをキースイッチに挿しこみます。
<br>
向きを戻して、他のキースイッチも取り付けします。
<br>
その際、ミドルプレート１の一部が外れていても大丈夫です。
<br>

すべてのキースイッチを取り付けたら、先ほど作ったアクリルケースと組み合わせます。その際、外れていたミドルプレート１の一部を忘れないで組み合わせてください。

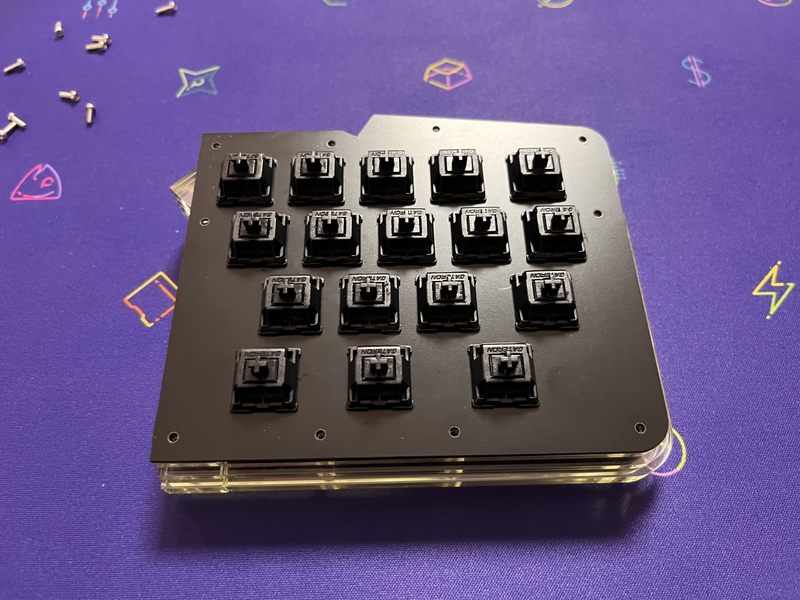
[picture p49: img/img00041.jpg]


トッププレートをのせます。

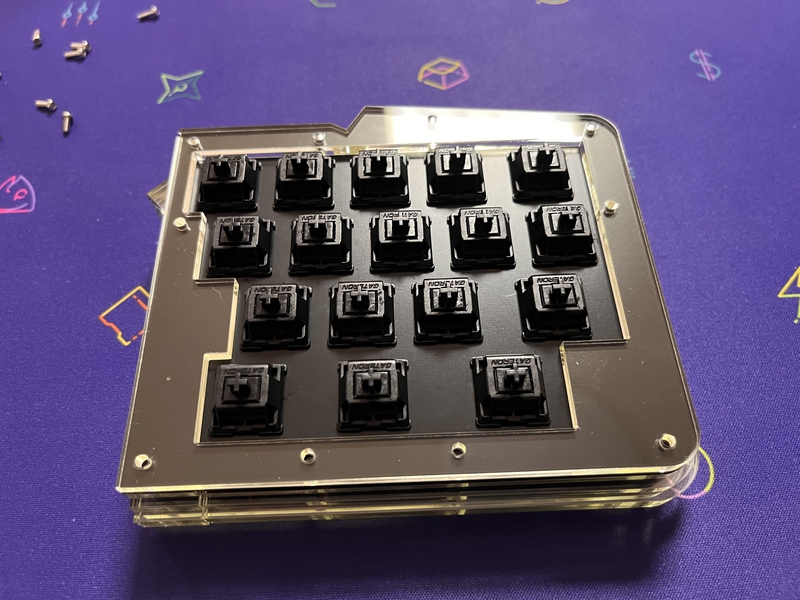
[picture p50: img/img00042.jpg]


M２ネジで固定します。

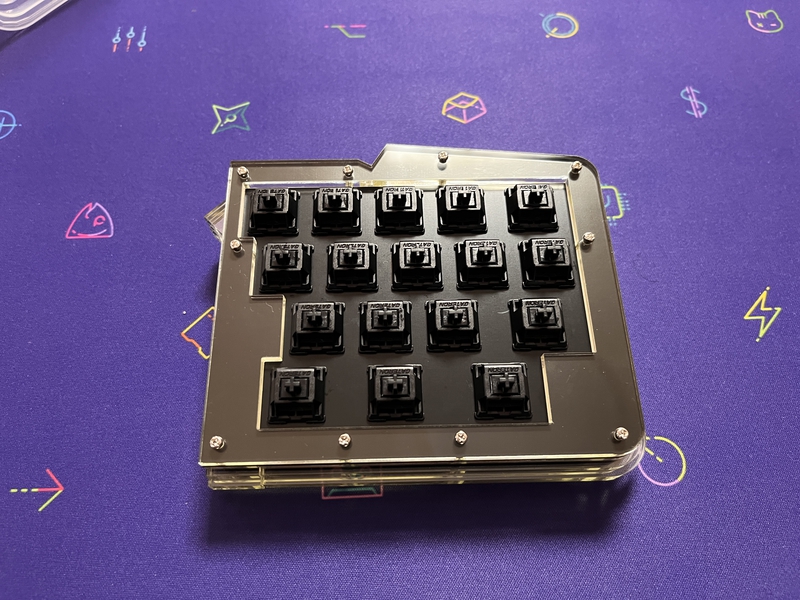
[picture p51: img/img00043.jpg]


### 9 キーキャップ等の装着

お好みのキーキャップ、TRRSケーブル、USBケーブル棟を装着して完成です。
<br>
このキーキャップは設計のきっかけとなった、DSS Microです。

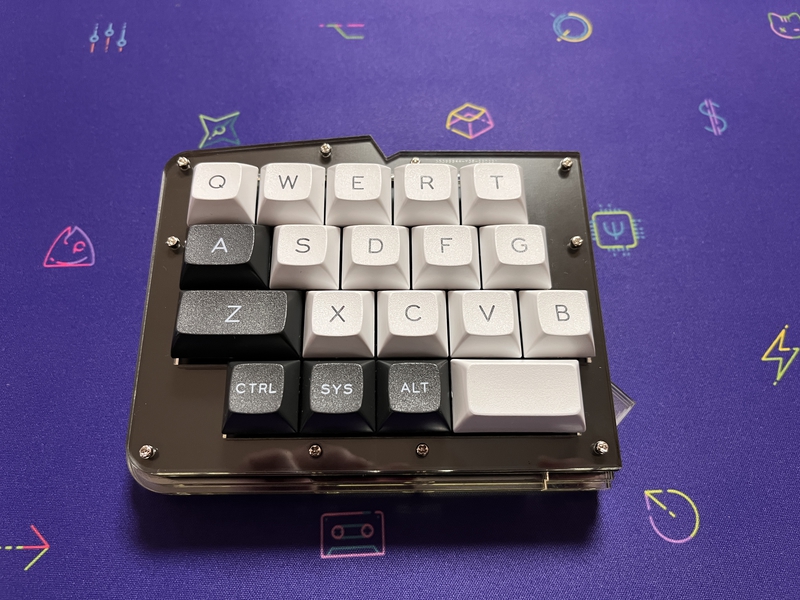
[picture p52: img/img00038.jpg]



ゴム足をつけるときは、この位置がおすすめです。



完成したら、cool936を楽しんでください。



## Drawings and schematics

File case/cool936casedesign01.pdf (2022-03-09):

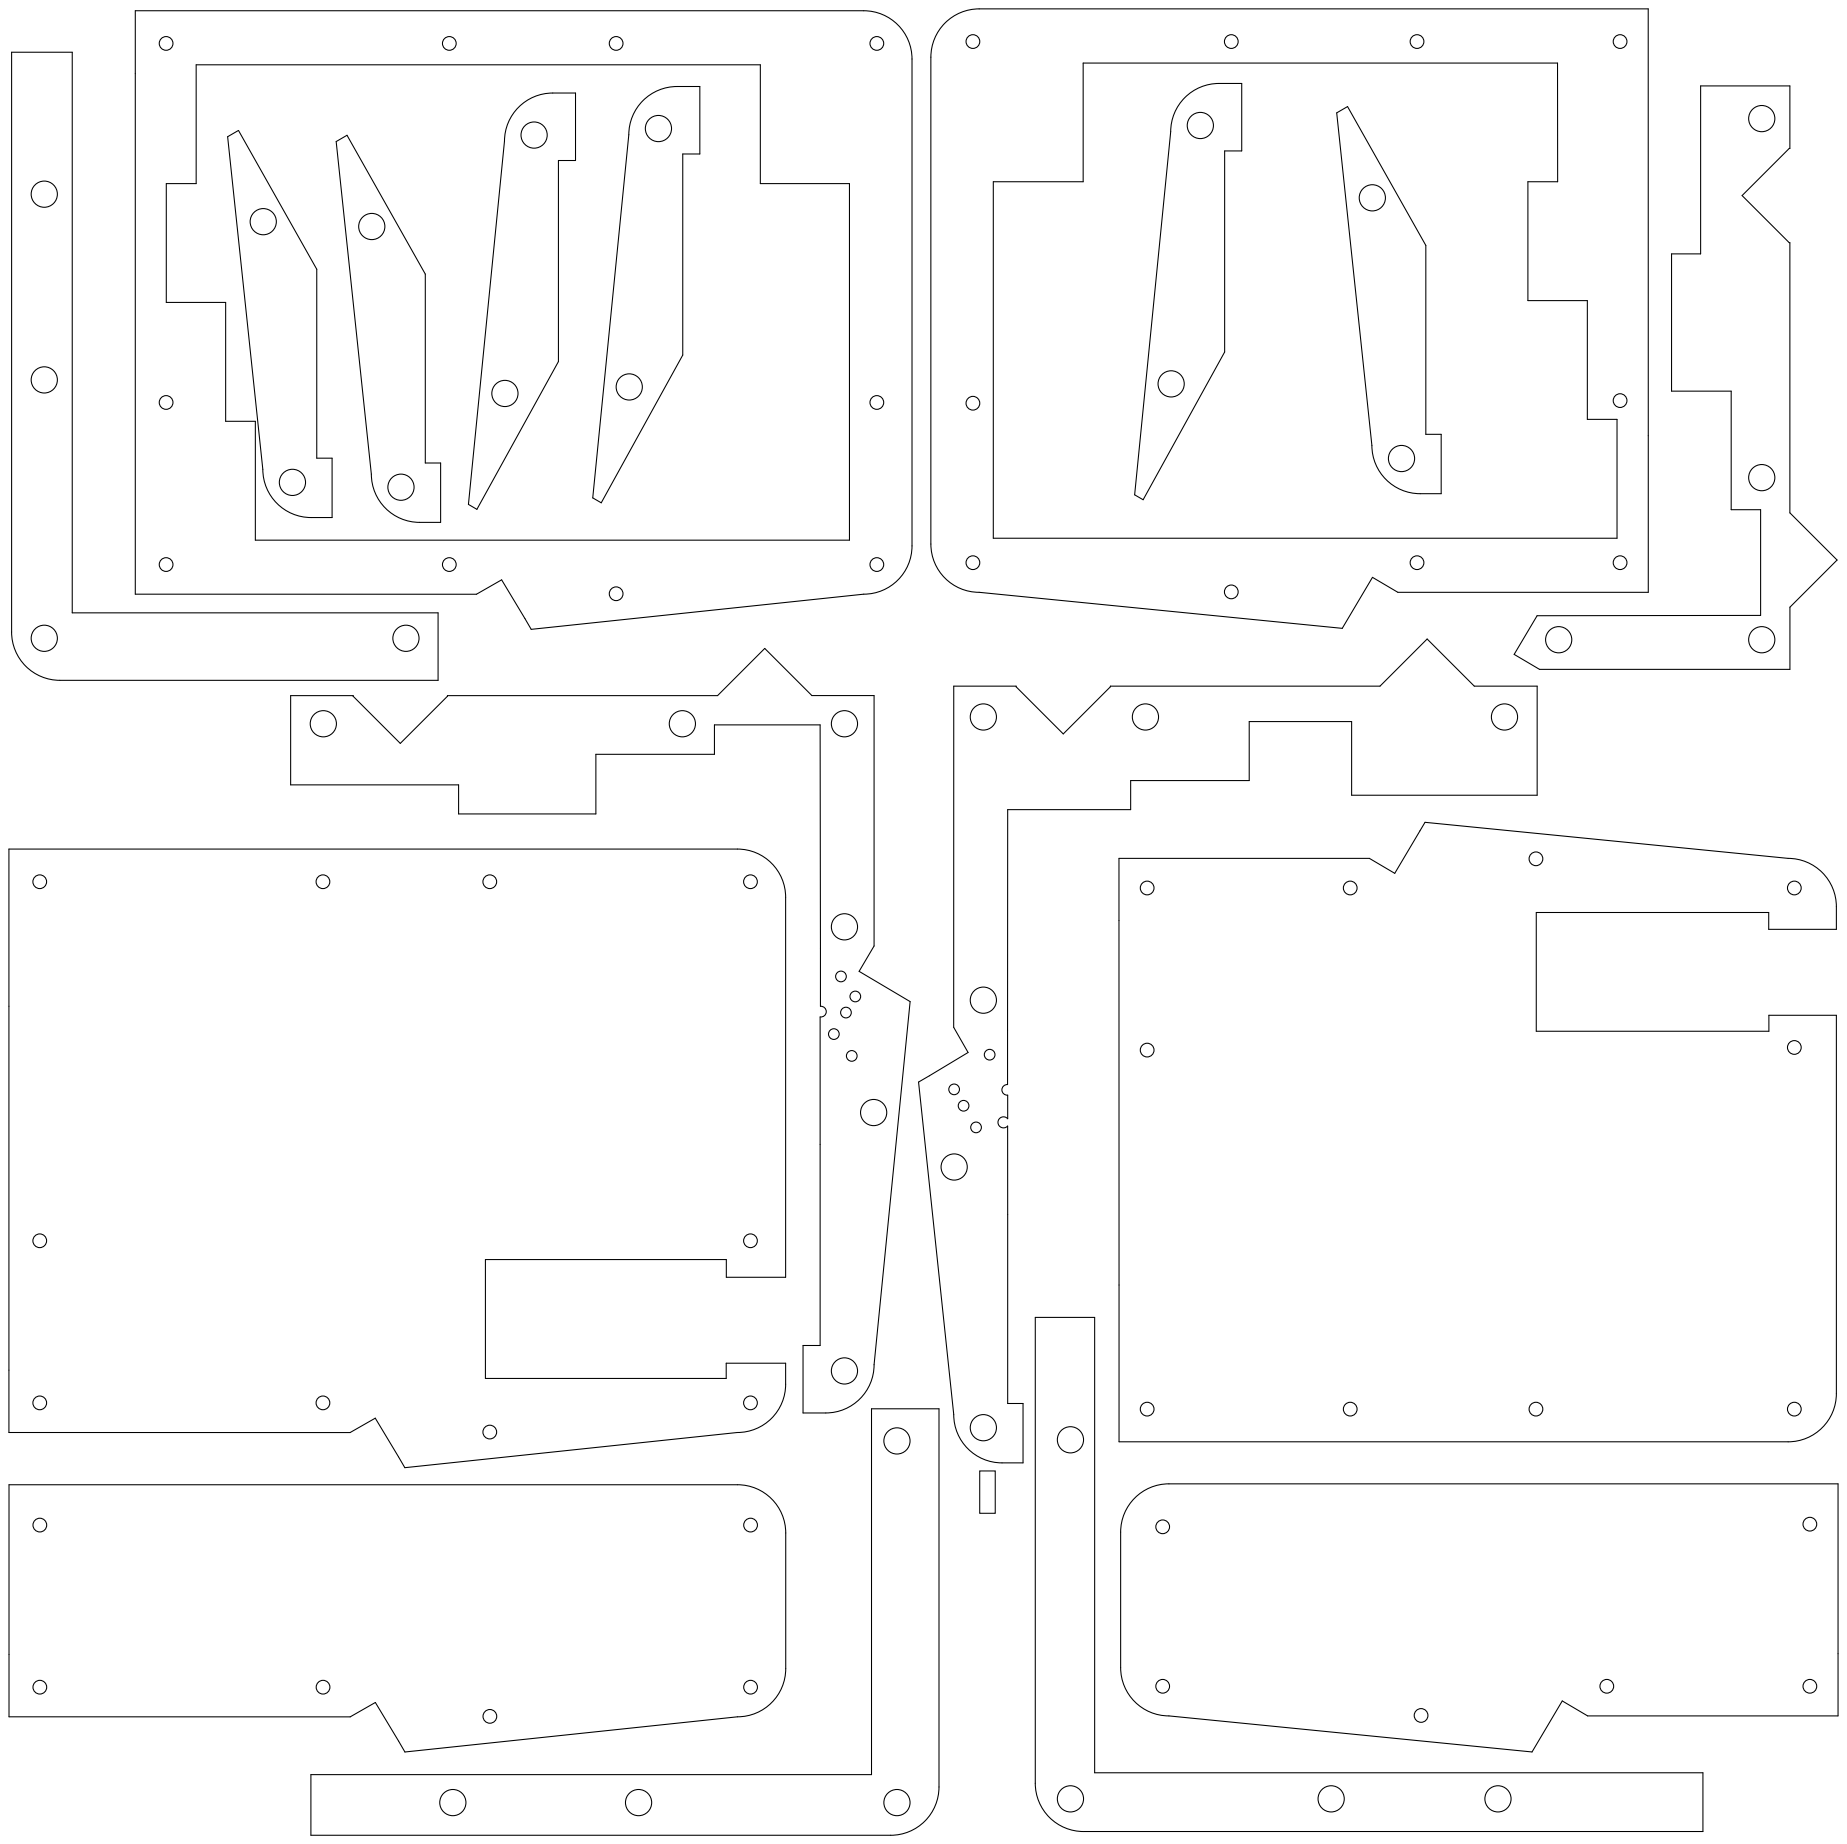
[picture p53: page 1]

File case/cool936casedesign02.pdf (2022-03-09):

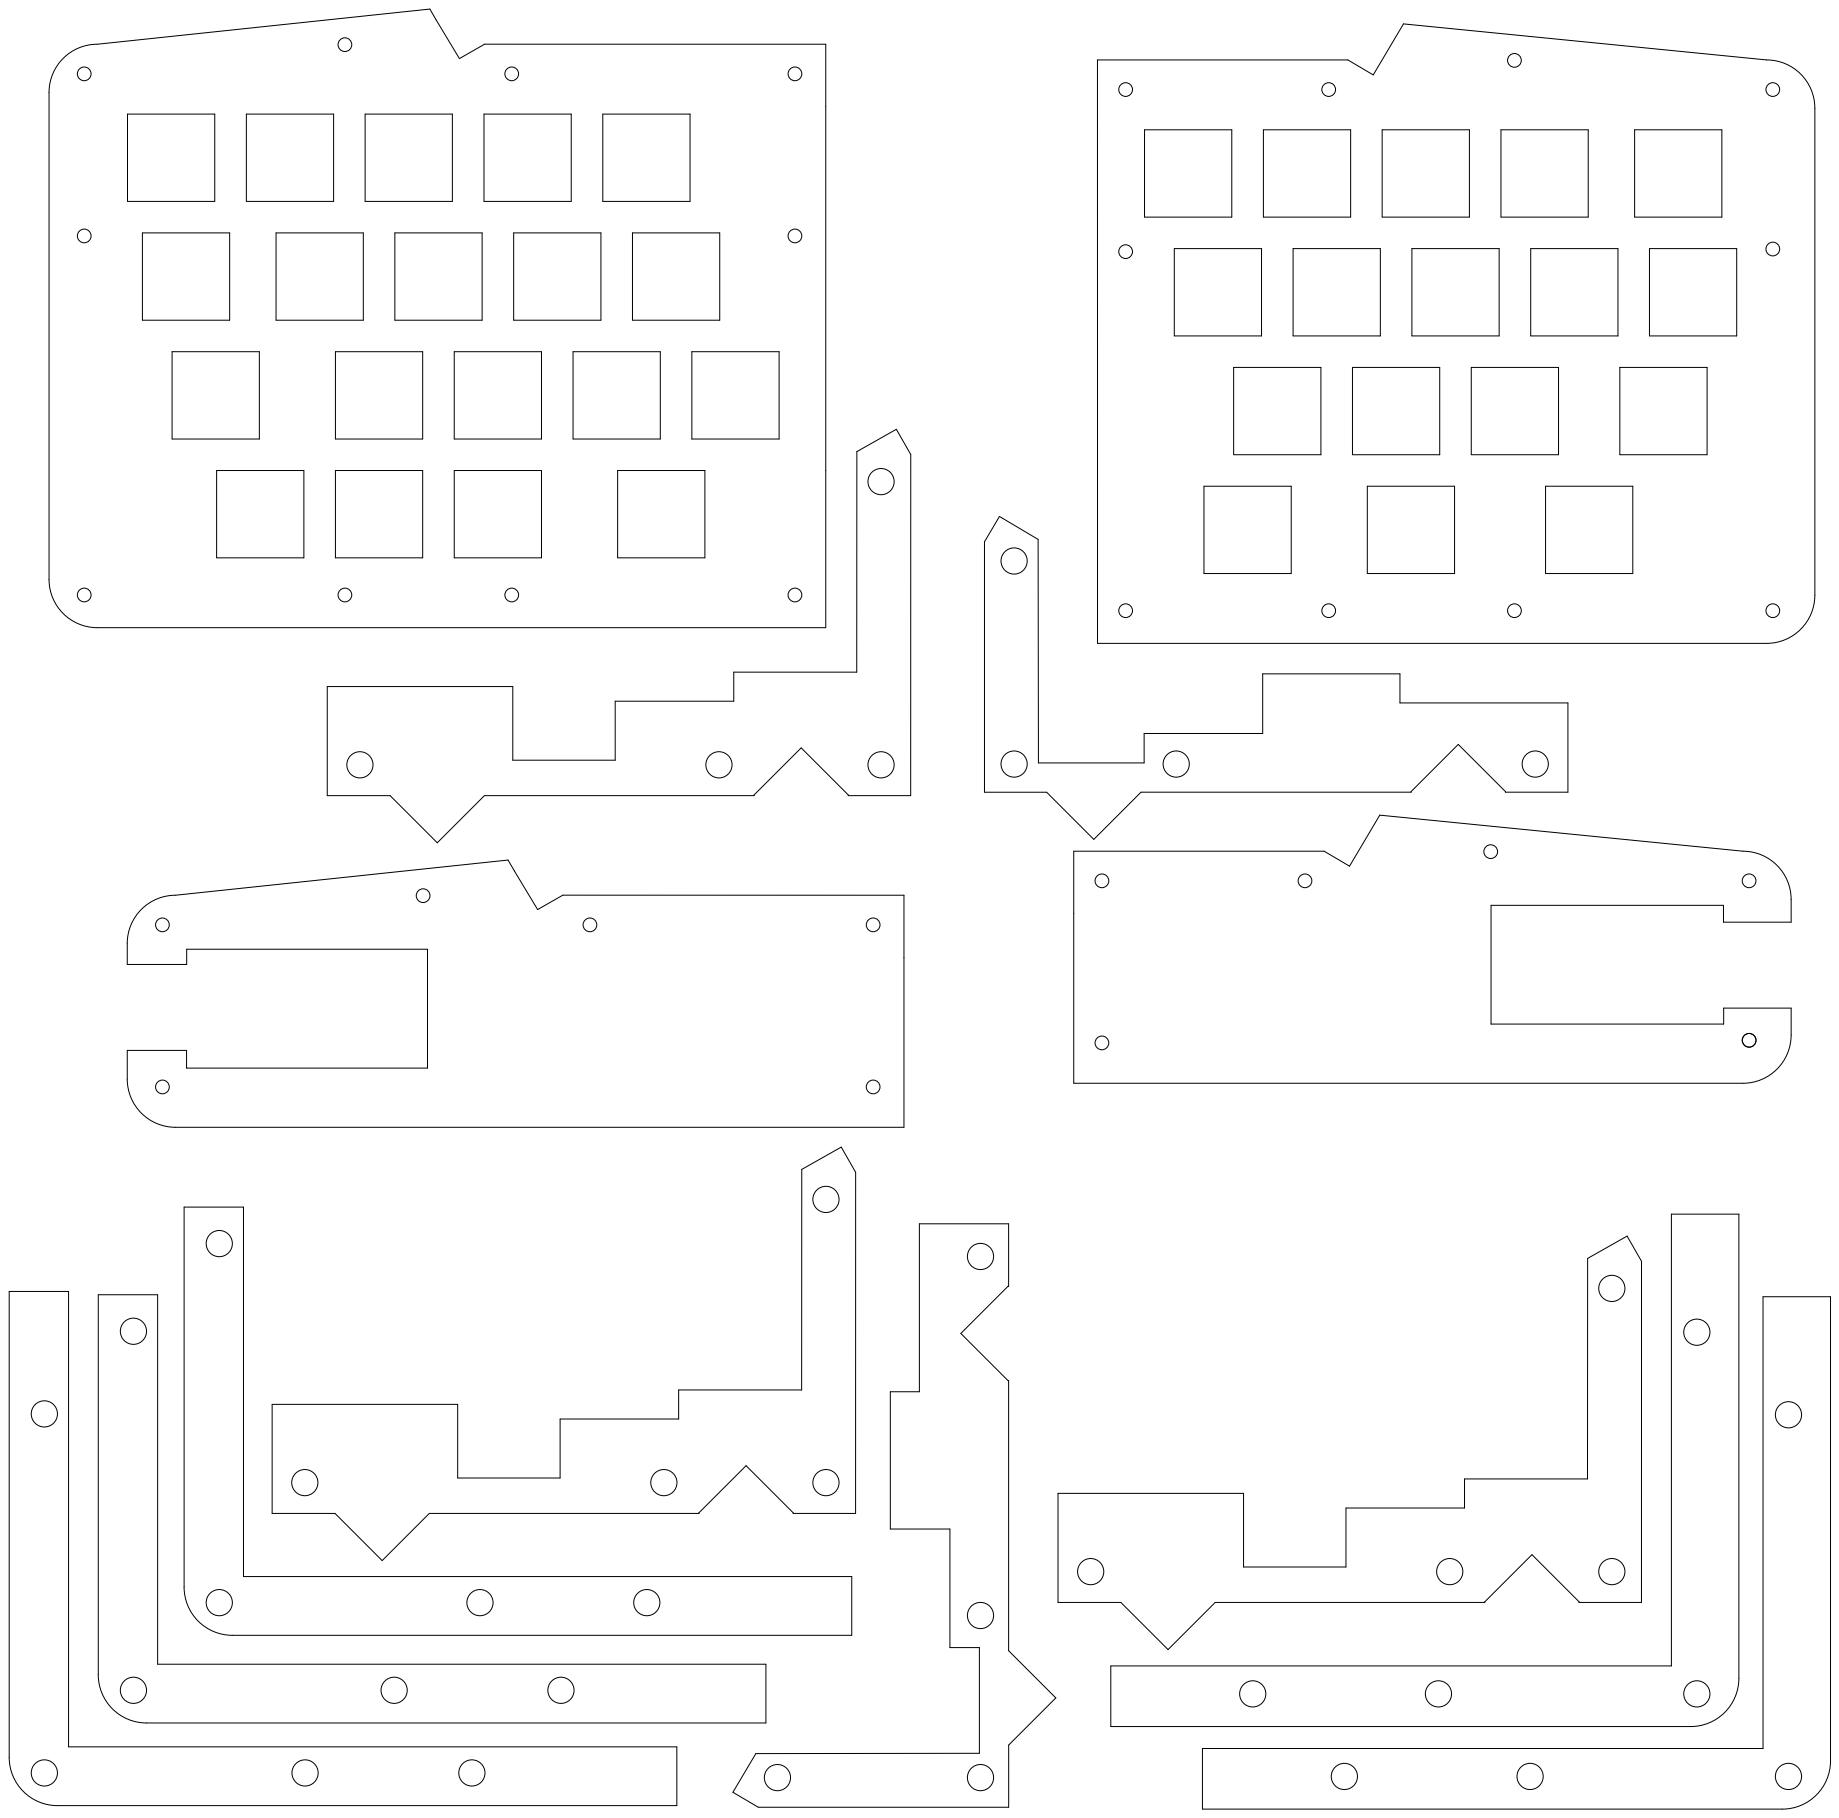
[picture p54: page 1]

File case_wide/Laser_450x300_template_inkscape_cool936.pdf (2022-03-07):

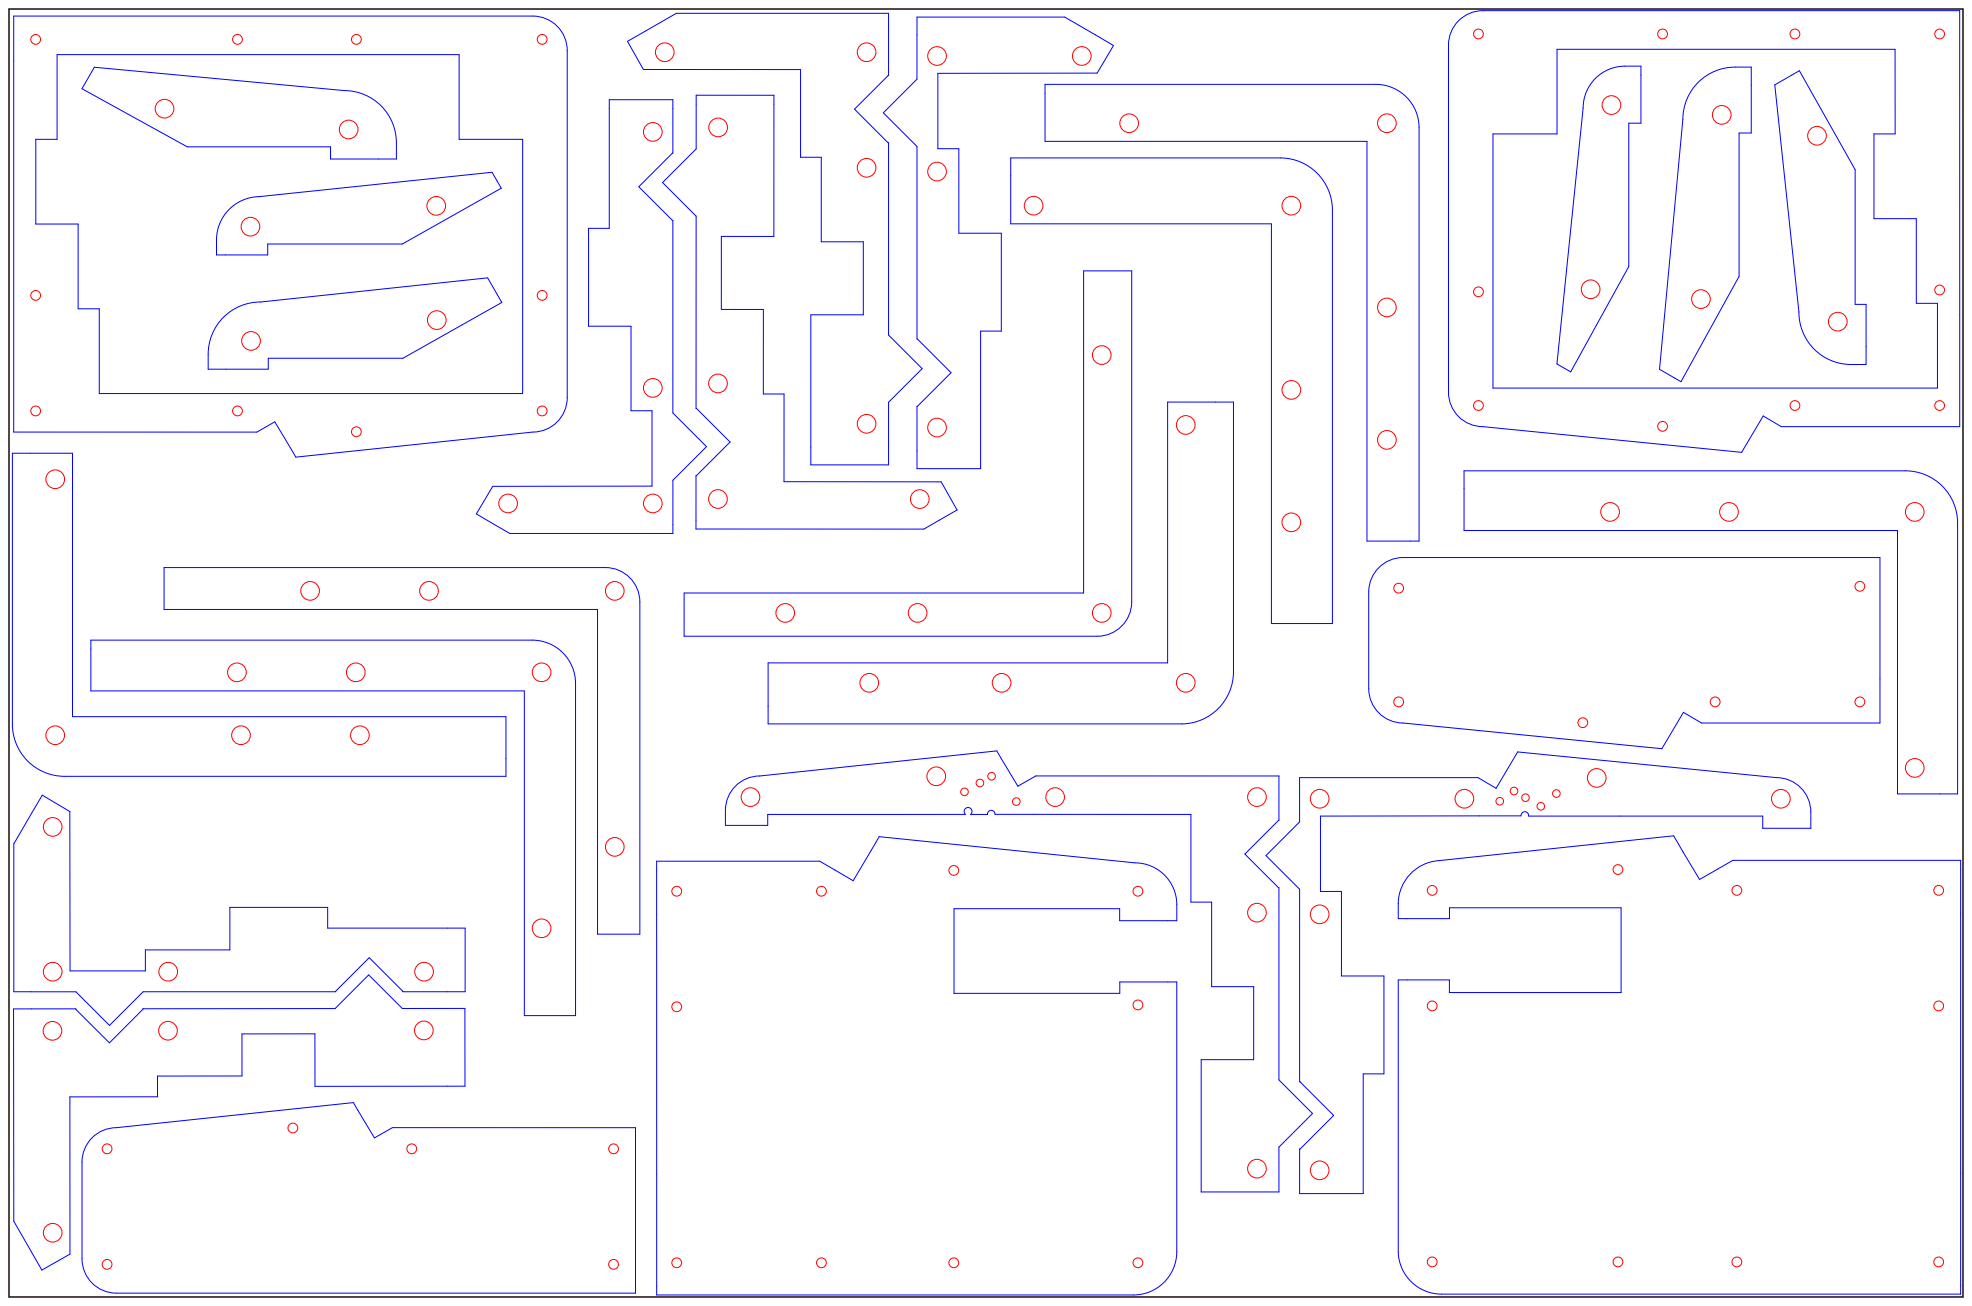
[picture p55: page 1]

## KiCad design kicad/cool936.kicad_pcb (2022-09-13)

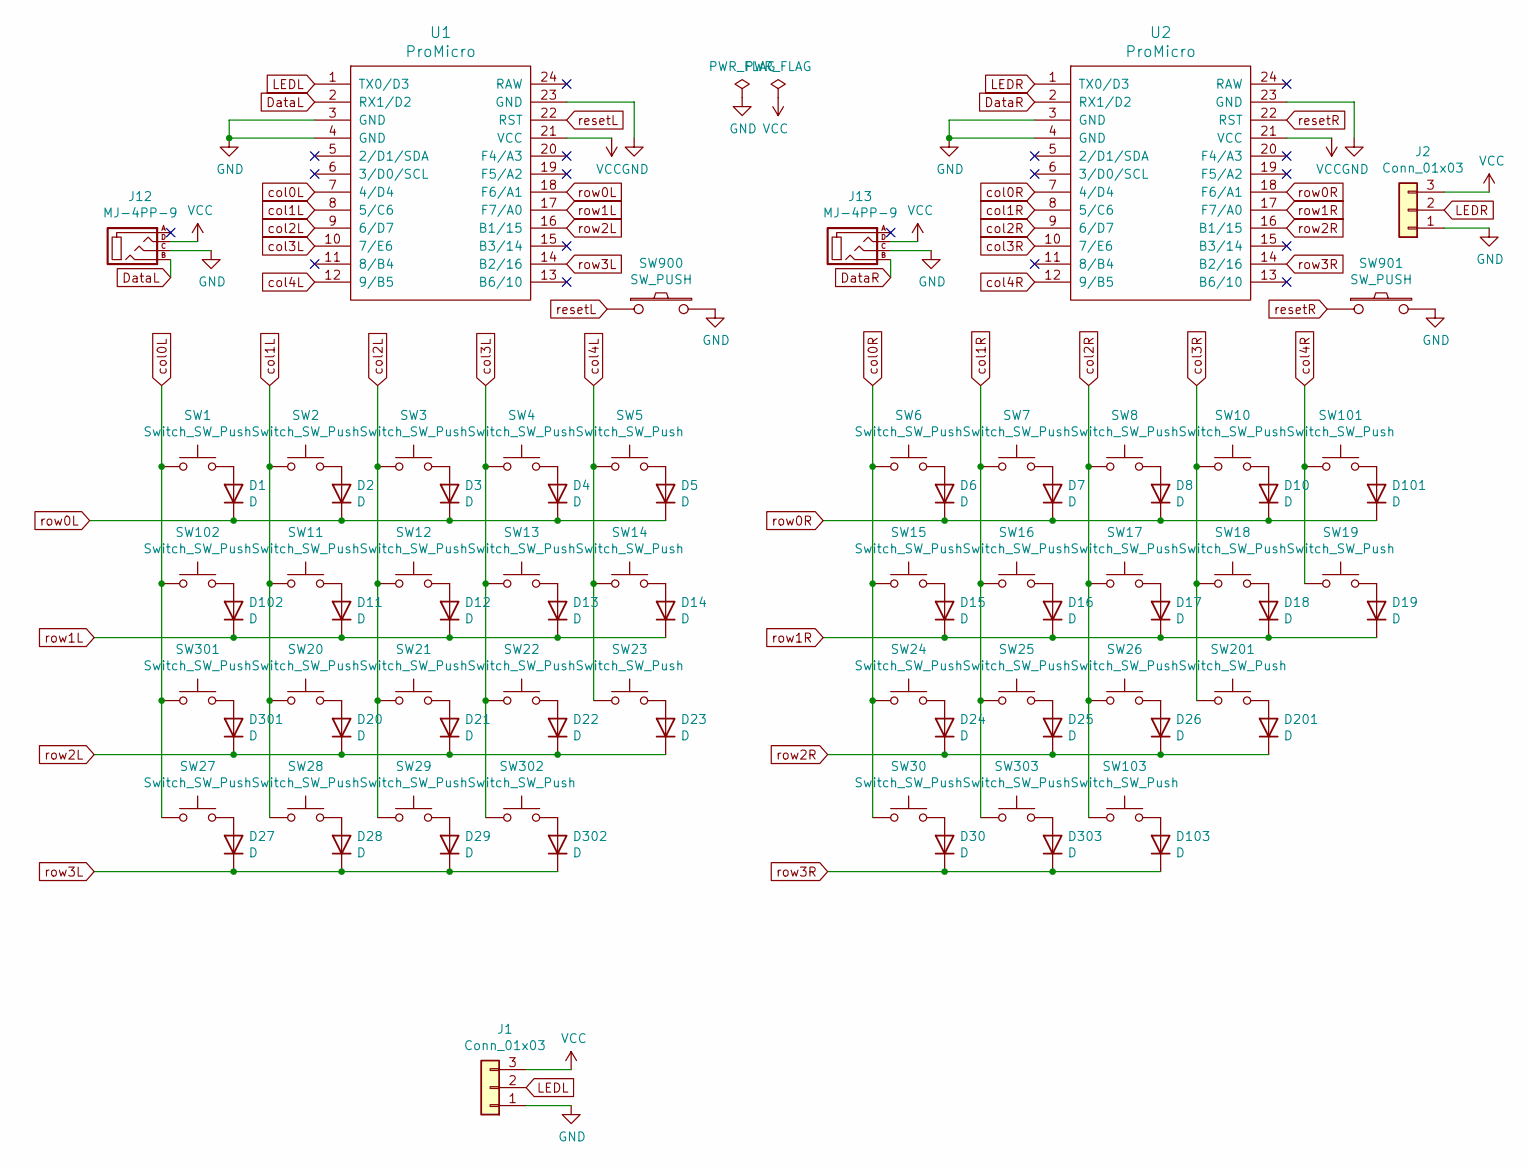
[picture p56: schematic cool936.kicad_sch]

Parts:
D1, D2, D3, D4, D5, D6, D7, D8, D10, D11, D12, D13, D14, D15, D16, D17, D18, D19, D20, D21, D22, D23, D24, D25, D26, D27, D28, D29, D30, D101, D102, D103, D201, D301, D302, D303: D; D3_TH_SMD
J1, J2: Conn_01x03; StripLED_1side
J12, J13: MJ-4PP-9; MJ-4PP-9_1side
SW1, SW2, SW3, SW4, SW5, SW6, SW7, SW8, SW10, SW11, SW12, SW13, SW14, SW15, SW16, SW17, SW18, SW19, SW20, SW21, SW22, SW23, SW24, SW25, SW26, SW27, SW28, SW29, SW30, SW101, SW102, SW103, SW201, SW301, SW302, SW303: Switch_SW_Push; CherryMX_Hotswap_kimura
SW900, SW901: SW_PUSH; ResetSW_1side
U1, U2: ProMicro; ProMicro_v3_kimura_for_cool936

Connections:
DataL: J12.B, U1.2 (RX1/D2)
DataR: J13.B, U2.2 (RX1/D2)
GND: J1.1, J2.1, J12.C, J13.C, SW900.2, SW901.2, U1.3 (GND), U1.4 (GND), U1.23 (GND), U2.3 (GND), U2.4 (GND), U2.23 (GND)
LEDL: J1.2, U1.1 (TX0/D3)
LEDR: J2.2, U2.1 (TX0/D3)
unnamed: D1.2 (A), SW1.2
unnamed: D2.2 (A), SW2.2
unnamed: D3.2 (A), SW3.2
unnamed: D4.2 (A), SW4.2
unnamed: D5.2 (A), SW5.2
unnamed: D6.2 (A), SW6.2
unnamed: D7.2 (A), SW7.2
unnamed: D8.2 (A), SW8.2
unnamed: D10.2 (A), SW10.2
unnamed: D11.2 (A), SW11.2
unnamed: D12.2 (A), SW12.2
unnamed: D13.2 (A), SW13.2
unnamed: D14.2 (A), SW14.2
unnamed: D15.2 (A), SW15.2
unnamed: D16.2 (A), SW16.2
unnamed: D17.2 (A), SW17.2
unnamed: D18.2 (A), SW18.2
unnamed: D19.2 (A), SW19.2
unnamed: D20.2 (A), SW20.2
unnamed: D21.2 (A), SW21.2
unnamed: D22.2 (A), SW22.2
unnamed: D23.2 (A), SW23.2
unnamed: D24.2 (A), SW24.2
unnamed: D25.2 (A), SW25.2
unnamed: D26.2 (A), SW26.2
unnamed: D27.2 (A), SW27.2
unnamed: D28.2 (A), SW28.2
unnamed: D29.2 (A), SW29.2
unnamed: D30.2 (A), SW30.2
unnamed: D101.2 (A), SW101.2
unnamed: D102.2 (A), SW102.2
unnamed: D103.2 (A), SW103.2
unnamed: D201.2 (A), SW201.2
unnamed: D301.2 (A), SW301.2
unnamed: D302.2 (A), SW302.2
unnamed: D303.2 (A), SW303.2
VCC: J1.3, J2.3, J12.D, J13.D, U1.21 (VCC), U2.21 (VCC)
col0L: SW1.1, SW27.1, SW102.1, SW301.1, U1.7 (4/D4)
col0R: SW6.1, SW15.1, SW24.1, SW30.1, U2.7 (4/D4)
col1L: SW2.1, SW11.1, SW20.1, SW28.1, U1.8 (5/C6)
col1R: SW7.1, SW16.1, SW25.1, SW303.1, U2.8 (5/C6)
col2L: SW3.1, SW12.1, SW21.1, SW29.1, U1.9 (6/D7)
col2R: SW8.1, SW17.1, SW26.1, SW103.1, U2.9 (6/D7)
col3L: SW4.1, SW13.1, SW22.1, SW302.1, U1.10 (7/E6)
col3R: SW10.1, SW18.1, SW201.1, U2.10 (7/E6)
col4L: SW5.1, SW14.1, SW23.1, U1.12 (9/B5)
col4R: SW19.1, SW101.1, U2.12 (9/B5)
resetL: SW900.1, U1.22 (RST)
resetR: SW901.1, U2.22 (RST)
row0L: D1.1 (K), D2.1 (K), D3.1 (K), D4.1 (K), D5.1 (K), U1.18 (F6/A1)
row0R: D6.1 (K), D7.1 (K), D8.1 (K), D10.1 (K), D101.1 (K), U2.18 (F6/A1)
row1L: D11.1 (K), D12.1 (K), D13.1 (K), D14.1 (K), D102.1 (K), U1.17 (F7/A0)
row1R: D15.1 (K), D16.1 (K), D17.1 (K), D18.1 (K), D19.1 (K), U2.17 (F7/A0)
row2L: D20.1 (K), D21.1 (K), D22.1 (K), D23.1 (K), D301.1 (K), U1.16 (B1/15)
row2R: D24.1 (K), D25.1 (K), D26.1 (K), D201.1 (K), U2.16 (B1/15)
row3L: D27.1 (K), D28.1 (K), D29.1 (K), D302.1 (K), U1.14 (B2/16)
row3R: D30.1 (K), D103.1 (K), D303.1 (K), U2.14 (B2/16)

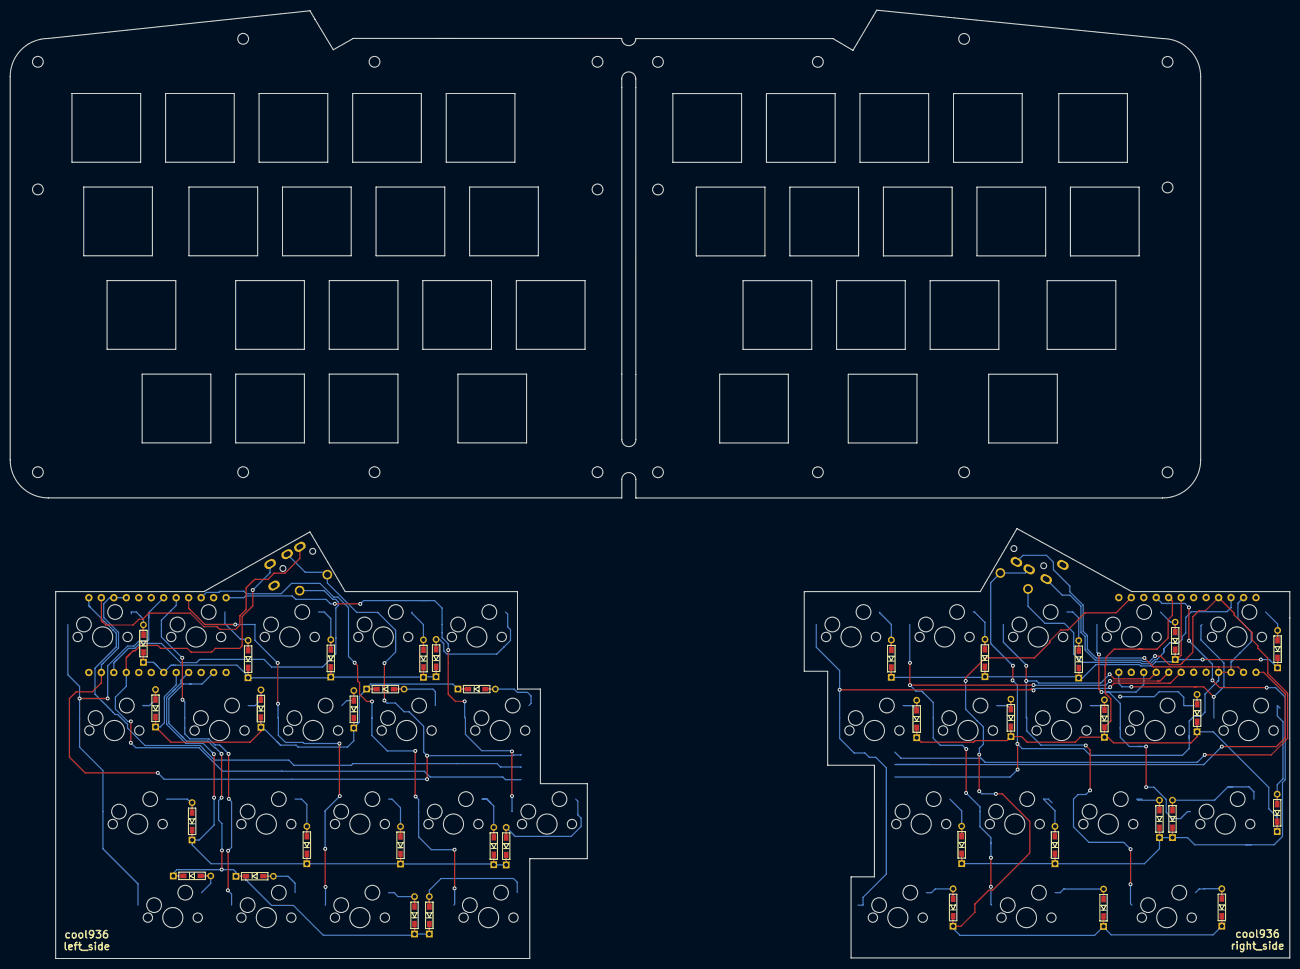
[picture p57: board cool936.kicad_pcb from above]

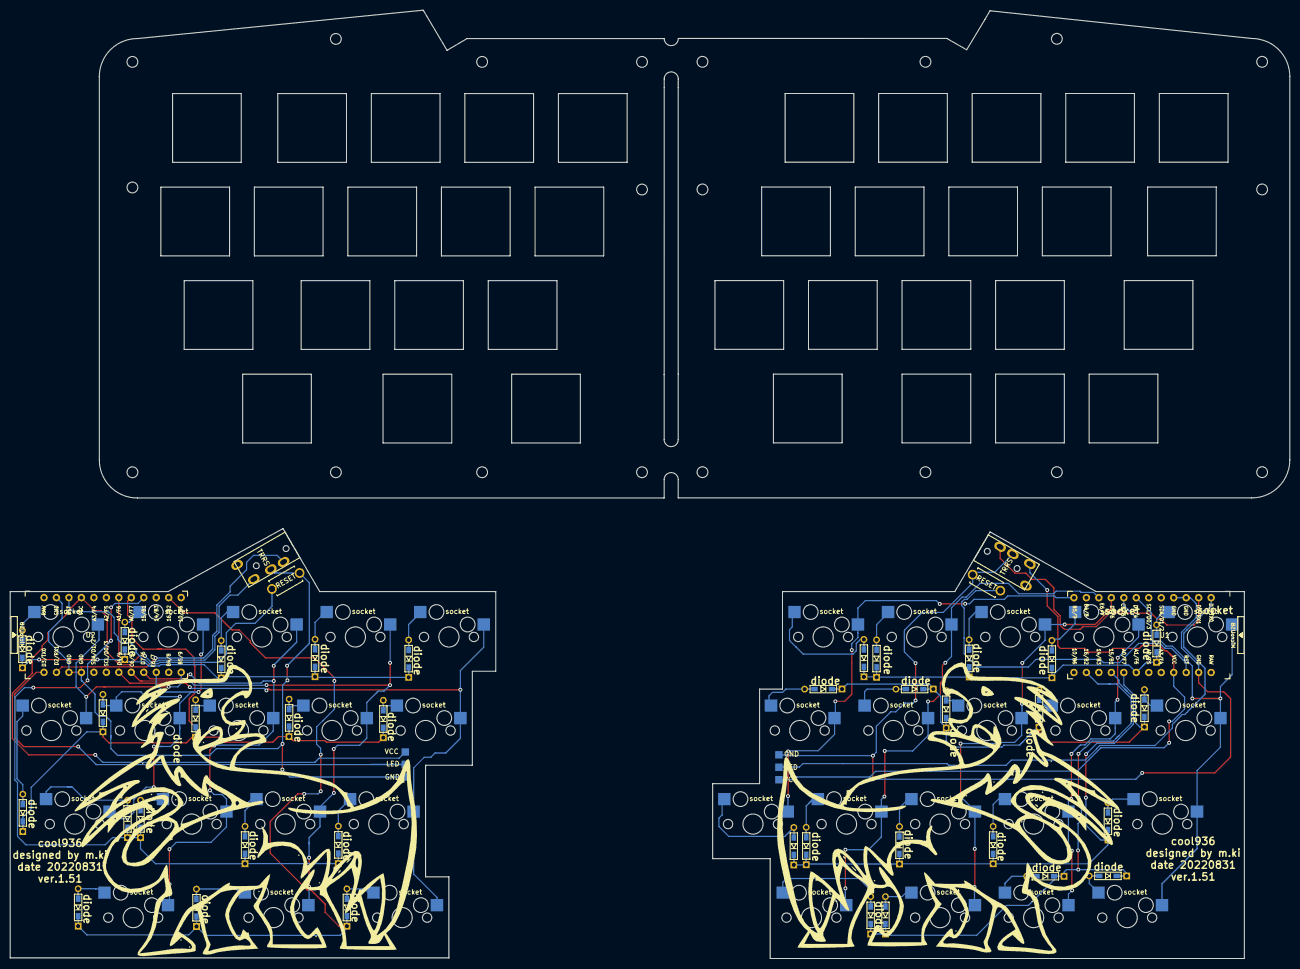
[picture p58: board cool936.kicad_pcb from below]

Board: 2 copper layers, 260.6 x 193.1 mm, 80 parts (6 on the bottom side), 62 nets.

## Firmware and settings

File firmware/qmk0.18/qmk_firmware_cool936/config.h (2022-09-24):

// Copyright 2022 m.ki (@telzo2000)
// SPDX-License-Identifier: GPL-2.0-or-later

#pragma once

#include "config_common.h"

/* USB Device descriptor parameter */
#define VENDOR_ID    0x4D43
#define PRODUCT_ID   0x0936
#define DEVICE_VER   0x0001
#define MANUFACTURER telzo2000
#define PRODUCT      cool936

/* key matrix size */
#define MATRIX_ROWS 8
#define MATRIX_COLS 5

/*
 * Keyboard Matrix Assignments
 *
 * Change this to how you wired your keyboard
 * COLS: AVR pins used for columns, left to right
 * ROWS: AVR pins used for rows, top to bottom
 * DIODE_DIRECTION: COL2ROW = COL = Anode (+), ROW = Cathode (-, marked on diode)
 *                  ROW2COL = ROW = Anode (+), COL = Cathode (-, marked on diode)
 *
 */
#define MATRIX_ROW_PINS { F6, F7, B1, B2 }
#define MATRIX_COL_PINS { D4, C6, D7, E6, B5 }
#define UNUSED_PINS

/* COL2ROW, ROW2COL */
#define DIODE_DIRECTION COL2ROW

/*
 * Split Keyboard specific options, make sure you have 'SPLIT_KEYBOARD = yes' in your rules.mk, and define SOFT_SERIAL_PIN.
 */
#define SOFT_SERIAL_PIN D2  // or D1, D2, D3, E6
#define RGBLIGHT_SPLIT
#define RGBLED_SPLIT { 6, 6 }
//#define LED_NUM_LOCK_PIN B0
//#define LED_CAPS_LOCK_PIN B1
//#define LED_SCROLL_LOCK_PIN B2
//#define LED_COMPOSE_PIN B3
//#define LED_KANA_PIN B4

//#define BACKLIGHT_PIN B7
//#define BACKLIGHT_LEVELS 3
//#define BACKLIGHT_BREATHING

#define RGB_DI_PIN D3

#ifdef RGB_DI_PIN
#    define RGBLED_NUM 16
#    define RGBLIGHT_HUE_STEP 16
#    define RGBLIGHT_SAT_STEP 16
#    define RGBLIGHT_VAL_STEP 16  
#    define RGBLIGHT_LIMIT_VAL 255 /* The maximum brightness level */
#    define RGBLIGHT_SLEEP  /* If defined, the RGB lighting will be switched off when the host goes to sleep */
/*== all animations enable ==*/
//#    define RGBLIGHT_ANIMATIONS
/*== or choose animations ==*/
#    define RGBLIGHT_EFFECT_BREATHING
#    define RGBLIGHT_EFFECT_RAINBOW_MOOD
#    define RGBLIGHT_EFFECT_RAINBOW_SWIRL
#    define RGBLIGHT_EFFECT_SNAKE
#    define RGBLIGHT_EFFECT_KNIGHT
#    define RGBLIGHT_EFFECT_CHRISTMAS
#    define RGBLIGHT_EFFECT_STATIC_GRADIENT
#    define RGBLIGHT_EFFECT_RGB_TEST
#    define RGBLIGHT_EFFECT_ALTERNATING
/*== customize breathing effect ==*/
/*==== (DEFAULT) use fixed table instead of exp() and sin() ====*/
#    define RGBLIGHT_BREATHE_TABLE_SIZE 256      // 256(default) or 128 or 64
/*==== use exp() and sin() ====*/
#    define RGBLIGHT_EFFECT_BREATHE_CENTER 1.85  // 1 to 2.7
#    define RGBLIGHT_EFFECT_BREATHE_MAX    255   // 0 to 255
#endif

/* Debounce reduces chatter (unintended double-presses) - set 0 if debouncing is not needed */
#define DEBOUNCE 5

/* define if matrix has ghost (lacks anti-ghosting diodes) */
//#define MATRIX_HAS_GHOST

/* Mechanical locking support. Use KC_LCAP, KC_LNUM or KC_LSCR instead in keymap */
#define LOCKING_SUPPORT_ENABLE
/* Locking resynchronize hack */
#define LOCKING_RESYNC_ENABLE

/* If defined, GRAVE_ESC will always act as ESC when CTRL is held.
 * This is useful for the Windows task manager shortcut (ctrl+shift+esc).
 */
//#define GRAVE_ESC_CTRL_OVERRIDE

/*
 * Force NKRO
 *
 * Force NKRO (nKey Rollover) to be enabled by default, regardless of the saved
 * state in the bootmagic EEPROM settings. (Note that NKRO must be enabled in the
 * makefile for this to work.)
 *
 * If forced on, NKRO can be disabled via magic key (default = LShift+RShift+N)
 * until the next keyboard reset.
 *
 * NKRO may prevent your keystrokes from being detected in the BIOS, but it is
 * fully operational during normal computer usage.
 *
 * For a less heavy-handed approach, enable NKRO via magic key (LShift+RShift+N)
 * or via bootmagic (hold SPACE+N while plugging in the keyboard). Once set by
 * bootmagic, NKRO mode will always be enabled until it is toggled again during a
 * power-up.
 *
 */
//#define FORCE_NKRO

/*
 * Feature disable options
 *  These options are also useful to firmware size reduction.
 */

/* disable debug print */
//#define NO_DEBUG

/* disable print */
//#define NO_PRINT

/* disable action features */
//#define NO_ACTION_LAYER
//#define NO_ACTION_TAPPING
//#define NO_ACTION_ONESHOT

/* disable these deprecated features by default */
#define NO_ACTION_MACRO
#define NO_ACTION_FUNCTION

/* Bootmagic Lite key configuration */
//#define BOOTMAGIC_LITE_ROW 0
//#define BOOTMAGIC_LITE_COLUMN 0
